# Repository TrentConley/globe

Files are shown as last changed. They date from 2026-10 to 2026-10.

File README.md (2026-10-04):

# Travel Globe · Engineering prototype A0

- [Travel appearance simulator](https://trentconley.github.io/globe/)
- [Actual CAD assembly](https://trentconley.github.io/globe/engineering.html)
- [Engineering report](https://trentconley.github.io/globe/engineering-report.html)
- [CAD/source package](https://trentconley.github.io/globe/engineering-package.zip)
- [Manufacture the first sample — quote packs and test plan](https://trentconley.github.io/globe/sample-plan.html)
- [Small optical prototype package](https://trentconley.github.io/globe/optical-prototype-A0.zip)
- [Engineering source](https://github.com/TrentConley/globe/tree/master)

The full globe is not yet fabrication-ready. Matrix-board routing, polar coverage and physical optical/electrical/mechanical qualification remain on hold. The ten-cell optical test board is routed and independently checked; supplier qualification of its candidate LED is still required. No physical globe has been built or tested.

This branch contains the public static build. Phone edits on the appearance simulator stay in browser storage; this site is not connected to a hardware globe.

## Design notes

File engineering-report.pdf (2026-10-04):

# Travel globe — engineering prototype A0

A 305 mm travel globe with 25× terrain and approximately 50-mile illuminated footprints. This release contains actual CAD, a fitted optical prototype, a routed test PCB, controller software, and reproducible engineering checks. The complete globe is not yet released for fabrication. The dense matrix boards still have unrouted connections, the south-polar support region needs a coverage revision, and the real optical finish has not been tested.

Open the actual CAD assembly (http://127.0.0.1:4173/engineering.html) · Download the engineering package (http://127.0.0.1:4173/engineering-package.zip) · Travel appearance simulator (http://127.0.0.1:4173/index.html)

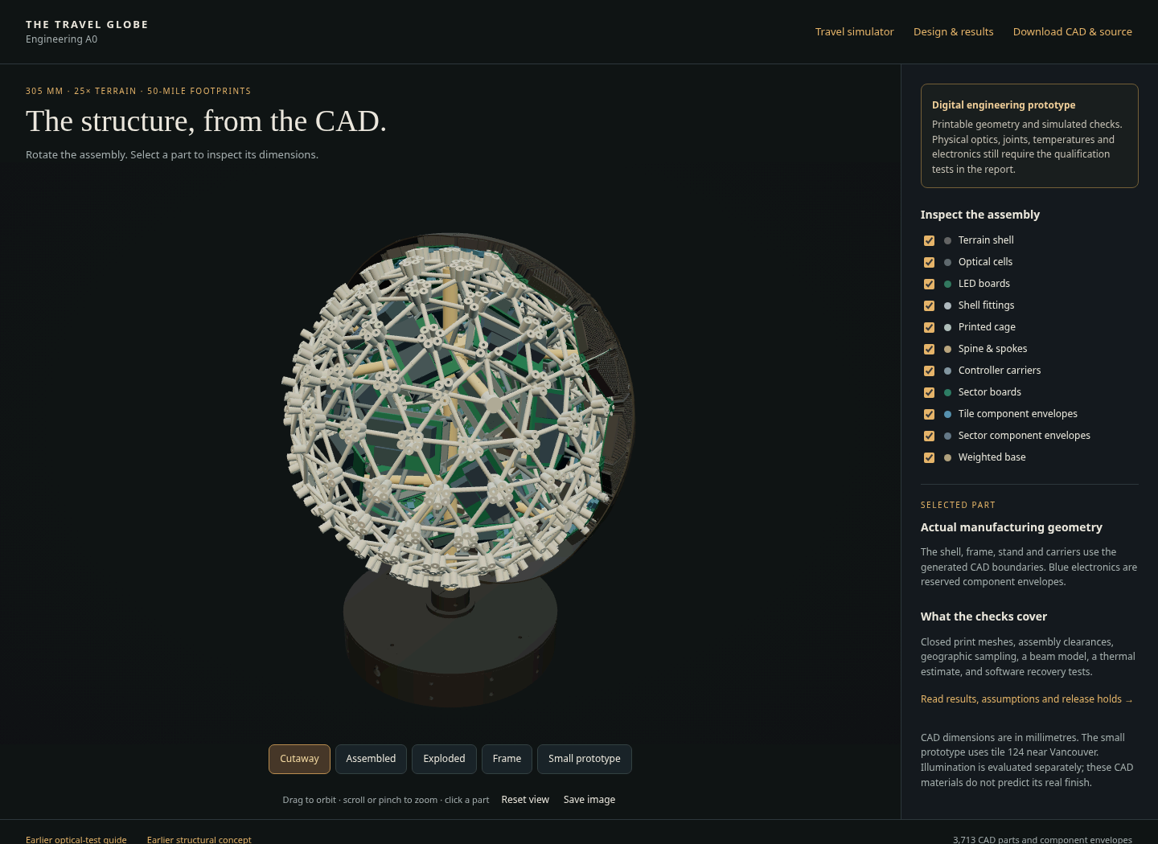
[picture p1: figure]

## What exists, and what the evidence means

Item | Status
Cage, stand, hubs, spokes, shell panels, baffles, controller carriers, prototype cradle | Parametric source and closed manufacturing meshes generated; assembly checks run
Terrain | Real sampled elevation, physically displaced at 25×; smooth inner sphere
Ten-cell optical test board | Routed; KiCad reports 0 violations and 0 unconnected items; Gerbers, drills, BOM and placement file included

Travel Globe A0 · Digital engineering prototype · 1 / 14

Item | Status
Six full-globe matrix board shapes | Placement, electrical connectivity and channel maps generated; routing incomplete — do not order
Mechanical simulation | Linear beam screening with a 3.5 kg supported mass; rigid-joint assumption
Thermal simulation | Two-node heat-balance estimate; no calibrated CFD or measured prototype temperatures
Optical simulation | Geometric apertures and parameter sensitivity; no measured resin, paint or LED data
Device software | 14 automated tests passed, including simulated transactions, interrupted storage, CRC errors and shutdown faults
Browser CAD viewer | Desktop and phone controls tested; reads actual generated meshes
Physical assembly, light output, print fit, component pinout/current, electrical commissioning | Not performed

The CAD viewer is an inspection tool. Its colors are material illustrations; it does not certify the finished globe's brightness or surface appearance. The travel simulator remains an ideal appearance preview.

## 1. Architecture and scale

At this scale, 50 miles is 1.926 mm of surface radius, or 3.852 mm across. A 2 mm planar LED grid becomes slightly wider at the spherical surface. A visited city is consequently a small group of cells, often one to five commanded emitters. Two nearby visits can merge. There are no connecting route lines and no country-wide fill.

The structure uses a frequency-four icosahedral lattice: 320 triangular tile positions, 162 frame nodes and 480 struts. Detailed Natural Earth coastlines select 226 populated tiles containing 33,406 emitters. Six repeated PCB/baffle shapes cover these positions. Many emitters on coastal boards remain off. The denser coastline data adds small-island coverage that the earlier coarse mask missed.

Twenty removable terrain panels correspond to the original icosahedron faces. Eight PA12 cage sections bolt together around a central aluminum spine. Ten aluminum spokes connect two split hubs to the cage. Twenty service carriers hold the sector electronics inside the cage. A weighted base supports the spine without bearings or a motor.

Nominal parameter | A0 value
Sea-level outside diameter | 305 mm
Smooth shell inside radius | 151.5 mm
Terrain exaggeration | 25×
Maximum sampled relief | Approximately 3.73 mm
Shell radial thickness | 1 mm at sea level, up to approximately 4.73 mm under the highest sampled relief
PCB corner radius | 144.5 mm
PCB thickness | 1 mm
LED pitch / optical opening at board | 2 mm / 1.6 mm

Travel Globe A0 · Digital engineering prototype · 2 / 14

Nominal parameter | | A0 value
Optical wall thickness | | 0.4 mm
Nominal baffle-to-shell clearance | | 0.35 mm
Nominal minimum panel-edge separation | | 0.5 mm
Cage vertex radius / strut diameter | | 132 mm / 3.6 mm
Spine | | 12 mm OD × 8 mm ID, 314 mm long
Spokes | | 8 mm OD × 4 mm ID aluminum tube
Base body | 200 mm diameter × 36 mm high, before feet
Steel ballast | 150 mm diameter × 6 mm thick, approximately 0.819 kg

All CAD coordinates use millimetres: +Z north, +X at latitude 0/longitude 0, +Y at longitude 90° east. The geometry
lies in its assembled coordinate system unless the filename begins | prototype- | or identifies a reusable local tile
part. Do not rescale STLs to inches.

## 2. Build the optical prototype first

This is the concrete first fabrication package, using tile 124 near Vancouver. It tests the real curvature, actual 2 mm lattice, magnetic seating and 25× terrain. Its simple ten-channel circuit avoids depending on the unfinished full-globe matrix PCB.

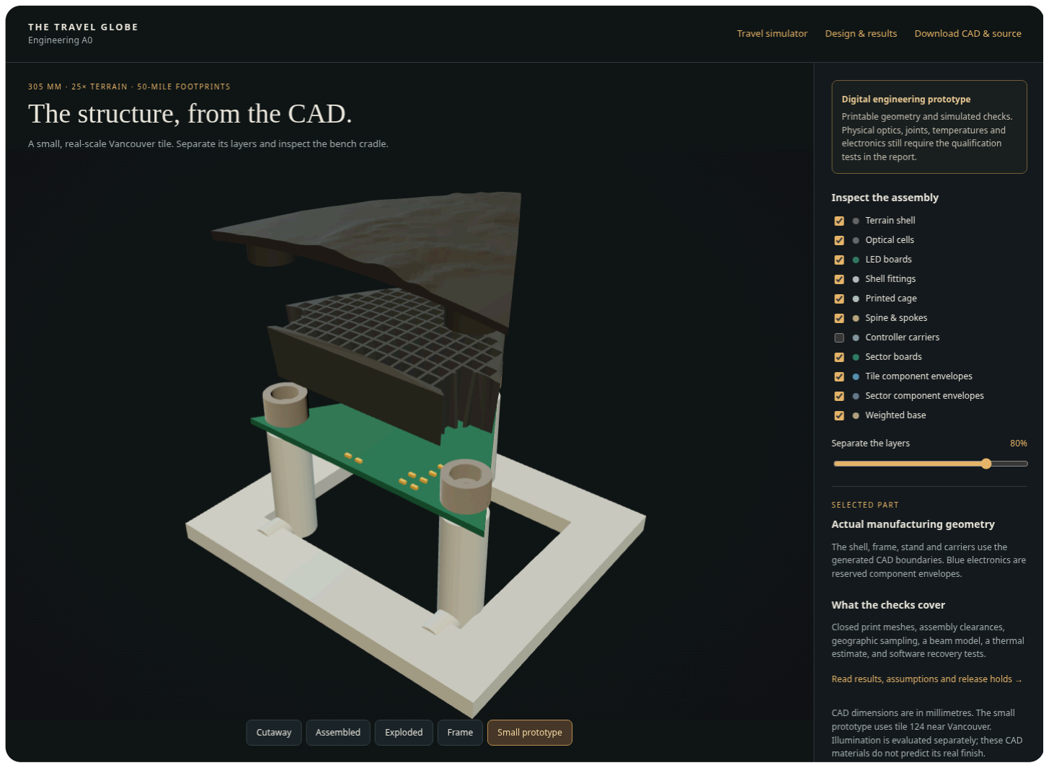
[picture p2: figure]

Travel Globe A0 · Digital engineering prototype · 3 / 14

Order or make the following:

Part | Quantity | Process

prototype-shell-vancouver-25x.stl

### 1 Clear/translucent SLA resin; preserve the smooth inner optical surface

prototype-shell-himalaya-25x.stl

### 1 Same resin and finish; thicker-relief comparison coupon on identical

curvature

baffle-type-02.stl | 1 Opaque black SLA/DLP resin; qualify 0.4 mm walls and clean every cell
prototype-cradle-type-02.stl | 1 | PA12 preferred; a rigid print-service alternative is acceptable for this bench fixture
magnet-seat-M2-4mm.stl | 3 PA12, with the supplied fit coupon
magnet-fit-coupon.stl | 1 | Same process as the seats
Optical bench PCB, 1 mm FR4 | Small service minimum | Supplied two-layer Gerbers/drills; outsource the 0402 LED and 0603 resistor assembly
4 mm diameter × 2 mm magnets | 6 | Matched pairs; verify polarity before retention

M2 × 22 countersunk screws and
M2 nuts

### 3 each The bench cradle has deeper nut pockets than the globe frame; confirm

| | head geometry and engagement

Adhesive rubber feet, at least 2 mm thick

### 4 Under the cradle; keep projecting screw tips clear of the table

Raspberry Pi Pico, USB cable, fine
insulated wire

### 1 set Bench control; no 12 V supply is used in this test

The bench BOM names Kingbright APHHS1005SYCK as a candidate amber/yellow 1005 LED. Its current manufacturer datasheet and polarity must be confirmed by the assembler. A nominal package name alone is not enough to approve substitution. The resistor is 1 kohm, 1%, 0603; RC0603FR-071KL is a suitable nominal specification. These components have not been physically tested here.

The bench board has only ten populated emitter positions. It cannot display arbitrary geography across the whole tile. The supplied Vancouver, Seattle, combined and individual-cell patterns use the selected positions. The cell spacing and optical stack are the same as the proposed full-globe design.

Assembly sequence:

1. Measure the print coupon's magnet pockets. Choose a retained fit that does not crack the part. Check baffle openings for cured resin or supports; do not coat or fill them.
2. Inspect the assembled PCB under magnification. Have the service verify cathode orientation. With power disconnected, confirm that no solder pad has a direct short to ground and that each drive pad reaches its LED through a 1 kohm resistor.
3. Connect board pad 0 to Pico GP0, 1 to GP1, continuing through 9 to GP9. Connect the board's GND pad to a Pico GND pin. The pad number denotes the GPIO, not the Pico's physical header-pin number. Solder from the rear and add strain relief to the cradle; do not pull on the small pads.
4. Install MicroPython on the Pico. Copy | firmware/ten-cell-bench/main.py | and | patterns.json | with
Thonny. The initial power-on state is off. In Thonny's Shell run | import main; main.show('walk-0', 0.1)
and repeat through | walk-9 | . Check every expected cell before fitting the shell.

Travel Globe A0 · Digital engineering prototype · 4 / 14

5. Seat three nuts in the cradle, install the PCB and magnet seats, and lightly seat the M2 × 22 screws. Fit the rubber feet so the screw tips cannot touch the table. The globe frame uses shorter M2 × 14 screws; do not interchange them. Use the printed post height to support the board; do not flex it to make a screw engage. Stop if the head or nut binds.
6. Fit the black baffle at its modeled position, with a nominal 0.1 mm bottom allowance above the PCB. Small removable dots at the outer edge may retain it. Keep adhesive out of cells and away from components.
7. Fit the magnets with paired polarity. The 5.0 mm seating rim is the mechanical stop; the frame magnet face is recessed at 4.8 mm. The mating shell boss seats on the rim, leaving a nominal 0.2 mm magnetic gap. Qualify removable retention before relying on the magnets to carry a panel.
8. Test the uncoated shell first: | main.show('vancouver', 0.1) | , then | seattle | , then | both | . A PWM level of 0.1
is a starting point, not a calibrated brightness match. | main.show('off', 0) | turns it off. The selected bench
pattern is saved for restart.
9. Apply a controlled transparent charcoal/smoke finish to a flat coupon and one shell. Start with a thin coat; record the product, dilution, number of coats and cure. An opaque black paint can make this design unusable. Compare a matte clear topcoat separately.
10. Repeat with the raised Himalaya coupon. Inspect whether thick relief becomes too dim or spreads light between cells. Keep fixed camera exposure when comparing samples.

The GPIO outputs are current-limited by the series resistors. Never connect this passive test board to the globe's 12 V rail. Its power comes from the USB-powered Pico's logic outputs. Outsourcing the tiny surface-mount assembly keeps the user's work to basic soldering and mechanical assembly.

## 3. Optical acceptance criteria

Do not infer optical success from the browser. The deep black cells reject most off-axis LED light. The Monte Carlo study predicts roughly percent-level direct passage through representative channels; measured LED intensity and finish transmission determine whether the result is attractive.

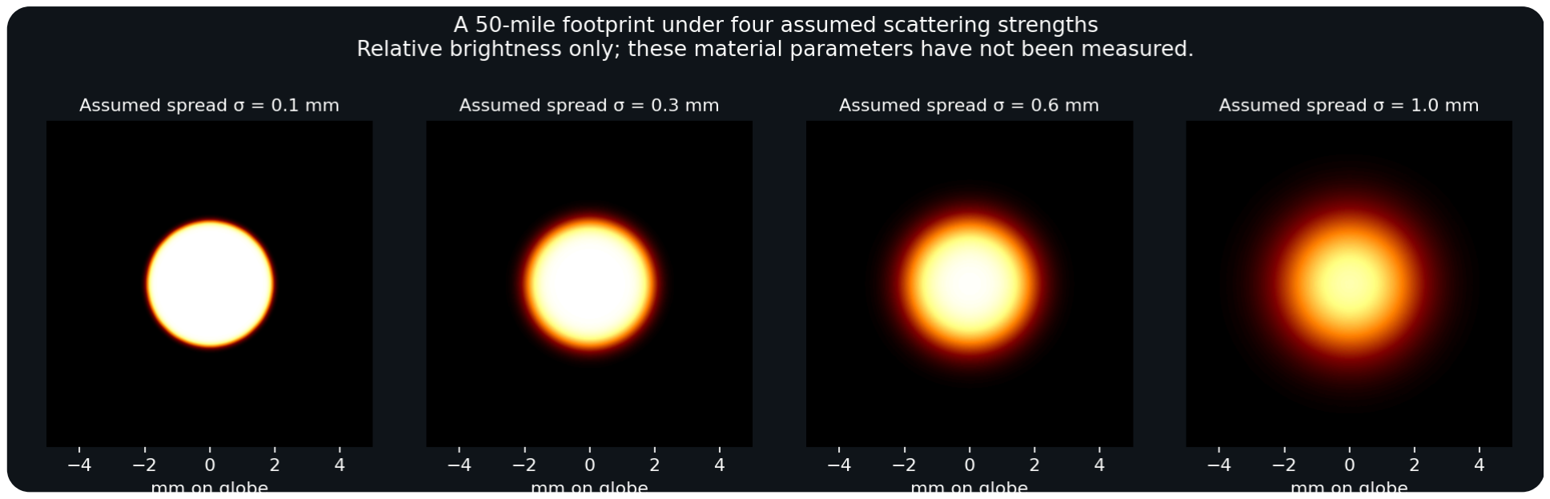
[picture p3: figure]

The shell's smooth inner surface makes the baffles repeatable but gives raised mountains a thicker light path. The absorption sweep quantifies the risk: increasing thickness from 1 to 4.73 mm leaves approximately 83%, 47%, 15%, or 2% of the flat-region transmission for assumed absorption coefficients of 0.05, 0.2, 0.5, or 1.0 per mm. Those coefficients are examples, not measured resin properties. Clear resin with a controlled outer tint is the starting material hypothesis.

Record these results in the supplied test log:

Travel Globe A0 · Digital engineering prototype · 5 / 14

At normal home viewing distance, Vancouver is a recognizable local patch and the neighboring unvisited cells stay dark enough to preserve its location.
Vancouver and Seattle can be recognized separately, and together create an understandable combined area without implying all of Canada is visited.
Individual lit cells do not make the entire shell glow. As an initial measurable target, the brightest adjacent uncommanded cell should stay below 15% of the commanded cell under fixed exposure.
A finished, unlit coupon looks charcoal rather than translucent white. The illuminated finish reads warm amber in the intended room lighting.
Raised terrain remains visibly lit. A starting comparison target is at least 40% of the nearby flat-region brightness before deciding whether electronic compensation is needed.
The baffle fits without pushing the shell outward. The seating rims, not the baffle walls, carry the shell. Record DC current, PWM setting, warm-up time and surface temperature for each comparison. Assess by eye as well as photographs; an attractive display is the purpose of the test.

If these fail, change resin/finish, optical opening, cell height or emission current and rerun the small test. A conformal thin-wall terrain shell is a possible later redesign, but it is not what these CAD files contain. After the small test passes, print one full-size terrain panel to check warpage and seam fit before ordering all twenty.

## 4. Full-globe mechanics and assembly

Use SLS/MJF PA12 for the cage, hubs, base parts and controller carriers. Material properties in the structural model are assumed lower-bound values, not print-service certification. The optical shell and baffle need different materials and finishing processes. Do not substitute opaque nylon for a light-transmitting shell.

The cage is split across three coordinate planes with a 0.05 mm modeling gap and twelve bolted side flanges. Unsupported sub-0.6 mm seam remnants are explicitly relieved and recorded in the mesh audit. PCB posts accept bottom-loaded M2 nuts; their support rods continue into the post above the nut recess. Bolt bores clear the projecting screw tips.

The purchased metal parts require cutting and drilling. The spine's 6 mm cable-exit port is 46 mm above its lower end, through one wall. Deburr it and fit abrasion protection. The base collar has an annular shoulder that carries the tube and a central wire passage. Spoke cut lengths and cross-hole centers come from the STEP/drawing files; use a drill jig to keep the two end holes aligned. The 8/4 mm spoke tube was selected to increase margin around the drilled joints.

Travel Globe A0 · Digital engineering prototype · 6 / 14

A0 mechanical dimensions · millimetres

Nominal dimensions from the CAD. Shop to confirm stock, drilling tolerance, edges and fitted joints. Ø305 sea level

376.5
before relief / feet

Ø200 base × 36

Hub center planes: Z = ±59.032
Globe center: Z = 0; base bottom: Z = −224 Spine end coordinates: −186 to +128 Purchased non-slip feet: qualify near R94

Spine · 12 OD / 8 ID

314

46

Ø6 cable port, one wall; deburr + grommet

### 10 spokes · 8 OD / 4 ID

102.264 cut length

Ø2.2 holes: 3.000 from hub end, 3.200 from cage end. Drill both walls. Hole axes parallel to assembled +Z.

Optical stack · local tile coordinates
PCB rear −1.0 · LED face 0 · package ~0.45 Seat head counterseat ~1.7 · magnet face 4.8 Seat rim / shell boss contact 5.0
Shell inner R151.5 · baffle top R151.15
Shell radial wall 1.0 to ~4.73 at 25× terrain

Fit-critical dimensions require the small coupon and measured supplier tolerances.

No general manufacturing tolerance is implied by decimal precision. Use a jig for short end distances.
The beam analysis omits hole stress concentration and joint slip. Proof-test the drilled tube / socket joint.
STEP defines the ballast holes and actual supports. This drawing is a dimensioned reference, not a certified fabrication release.

metal-cut-list.csv records the 102.264 mm nominal spoke length and the two cross-hole positions. Decimal precision describes the model, not a guaranteed manufacturing tolerance. The short distance from each hole to the tube end needs a drilled-joint proof test. Confirm fit before drilling all ten tubes.

Dry-assemble in this order: ballast and base; spine and two split hubs; ten spokes; eight cage sections; controller carriers; wiring trunks; populated PCB tiles; local optical baffles; magnet seats; terrain panels. Keep the base lid accessible until commissioning is complete. Install electronics and prove the light patterns before closing the shell.

The controller carriers have open saddles facing the cage. Push each onto its specified struts from inside, then retain it with 2.5 mm cable ties. Their 60 × 40 mm perfboards are double-sided assemblies: Pico inward, regulator/mux/transceiver outward. Module envelopes are reservations, not verified supplier STEP models. Clip and insulate solder leads so they cannot contact the Pico or cage. Verify actual purchased module dimensions before populating all twenty carriers.

Each populated tile has three supports. Ordinary PCB screws use the 1 mm head spacer to keep the head above the LED packages. At shell anchors, the magnet seat replaces this spacer. Anchors on an unpopulated ocean tile use a 1 mm dummy spacer in place of the absent PCB. There are sixty shell anchors in total. Preserve access to the screw beneath each magnet: qualify a removable retention method, not an irreversible fill of the screw cavity.

The nominal 0.5 mm panel seams and 0.35 mm baffle clearance are tolerance allowances. Confirm them against the service's cured dimensions, not just printer layer height. The three seating rims establish each shell panel's radial position. Magnetic friction and retention still need pull and service-cycle tests. Do not tighten a panel into place by bending it.

Travel Globe A0 · Digital engineering prototype · 7 / 14

## 5. Electronics and wiring

The full-globe architecture uses a Pi Zero 2 W in the base, twenty Pico sector controllers, one TCA9548A multiplexer per sector, and an IS31FL3741 per populated tile. Each sector has four independent I²C branches with
at most four tile addresses. | tile-schedule.csv | specifies every tile, board shape, multiplexer branch and address
jumper.

The full matrix boards are unfinished engineering candidates. Their pad-level netlists and placement files are included for review; full-globe Gerbers are deliberately absent. R_EXT is a provisional 2.2 kohm reference value and the firmware starts with current code 4. Current codes are not milliamps. Confirm the manufacturer specification, actual scan behavior, shutdown-pin behavior, thermal path and measured current before changing the current setting or releasing a batch.

A0 power and communications wiring

Low-voltage topology. Full-globe electronics remain on hold pending layout and hardware qualification.

External 12 V / ~36 W

Certified enclosed adapter M8 inlet → 2 A main fuse

INA260 0x40

IN+ from fused 12 V
IN− to relay COM; GND common

Normally-open relay

COM → NO only on enable
DC-rated 5 V coil candidate

Two power branches

A: 750 mA fuse → 10 sectors B: 750 mA fuse → 10 sectors 12 V, GND trunk
350 mA PTC at each sector

Independent 5 V regulator

From fused 12 V before relay Powers Pi and relay coil
Qualify 5 V / 2 A capacity

Pi Zero 2 W

GPIO2 SDA / GPIO3 SCL
GPIO17 → 1k → NPN base
USB → RS-485 adapter
FRAM 0x50 on 3.3 V I²C
Common low-voltage GND

Relay coil driver

+5 V → coil → NPN collector Emitter to GND; 100k B–E
Flyback diode across coil
Cathode at +5 V
Never drive coil from GPIO

Each sector ×20

350 mA PTC → 3.3 V buck
3.3 V → tile / logic rail
Schottky diode → Pico VSYS USB isolated from tile rail DS18B20 local sensor

One RS-485 daisy chain

Master end: 120 Ω termination
Bias once: 330 Ω A→3V3, B→GND Twisted pair A/B plus ground reference 120 Ω only at final sector; verify A/B

Sector Pico + 3.3 V transceiver

GP4 TX → DI; GP5 RX ← RO
GP6 → DE and /RE; 10k pull-down GP15 → DS18B20 data, 4.7k pull-up GP10–13 → branch SDB; 10k down

TCA9548A at 0x70

GP0 SDA, GP1 SCL; 100 kHz
GP14 reset + 10k pull-up; A0–A2 GND Upstream pull-up pair (account for module) 4 downstream buses × ≤4 addresses

One branch → tile daisy chain

6-pin JST-SH: 1 3V3 · 2 GND · 3 SDA 4 SCL · 5 SDB · 6 INTB provision
One 2.2k SDA/SCL pull-up pair per bus Exactly one JP per tile: 0x30–0x33 Target total branch cable ≤350 mm

Ten-cell bench is a separate, simple circuit

USB → Pico only; GP0–GP9 → matching pads 0–9
Each pad → 1 kohm resistor → one LED anode; all cathodes → common GND No matrix IC, 12 V input, relay or sector controller is used for this test
Load firmware/ten-cell-bench; outsource the tiny surface-mount assembly

Harness: use the tile, sector and I²C schedules. Check continuity and polarity before power.

Route the two fused +12 V feeds, ground and RS-485 pair through the deburred spine port. Add strain relief.
Power trunk: nominal AWG24; pair: flexible twisted insulated wire. Confirm voltage drop, connector current and cable fit. The software guard is not a certified safety circuit. Fuses, PTCs, external pull-downs and hardware fault tests are required. SDB / I²C behavior, real module envelopes, electrical schematic/ERC and full matrix routing remain release holds.
Tile connector pin | Signal

### 1 Local regulated 3.3 V

### 2 Ground

Travel Globe A0 · Digital engineering prototype · 8 / 14

Tile connector pin | Signal

### 3 SDA

### 4 SCL

### 5 Branch SDB shutdown

### 6 INTB, open-drain diagnostic provision; not used by A0 control software

Both tile connectors carry the same signals. Use precrimped 6-way JST-SH leads; confirm pin numbering at both ends rather than trusting wire colors. Bridge exactly one address jumper: JP1 = 0x30/GND, JP2 = 0x31/SCL, JP3 = 0x32/SDA, JP4 = 0x33/3.3 V. Address-to-SCL/SDA selection is a property of this IC; do not apply this scheme to an arbitrary replacement driver.

Sector Pico connection | Destination
GP0 / GP1 | TCA9548A SDA / SCL, 100 kHz
GP14 | TCA reset; active low, held high in normal operation
GP10–GP13 | SDB for mux branches 0–3
GP4 / GP5 | RS-485 transceiver DI / RO, UART1 at 115200 baud
GP6 | Joined DE and active-low RE
GP15 | DS18B20 data, 4.7 kohm pull-up to local 3.3 V
VSYS | Local supply through a Schottky isolation diode
GND | Common low-voltage ground

Use a 3.3 V MAX3485/SP3485-class transceiver, not a 5 V MAX485 module. A TCA9548A breakout such as Adafruit 2717 is a candidate; account for its installed pull-ups. Use one 2.2 kohm pull-up pair on each downstream branch and one upstream pair, rather than allowing every tile to add another pair. The harness schedule provides a wiring order and length allowance; confirm total branch length below the 350 mm design target and measure rise time during commissioning.

Use a 12 V trunk with local regulated 3.3 V converters; a D24V10F3-class module is the candidate envelope. Feed a Pico's VSYS through a Schottky diode so connecting USB cannot drive the shared 3.3 V LED rail backward. Flash and configure Picos with tile harnesses disconnected. Each sector input has a 350 mA PTC. Two base fuse branches, nominally 750 mA each, feed the twenty sectors. The current sensor and normally-open relay control the lighting branches, not the Pi's own supply.

RS-485 is one daisy chain. Terminate only its two physical ends with 120 ohms: the master end and the last sector
in | sector-harness.csv | . Install the idle bias once at the master, nominally 330 ohms from A to 3.3 V and 330 ohms
from B to ground. Include a ground reference with the twisted pair. Check the particular transceiver's A/B naming and idle receiver level before connecting all sectors.

The base uses a certified external 12 V, approximately 36 W adapter, a fused DC inlet, a separate 5 V Pi regulator, and a normally-open relay switched by a transistor with a flyback diode. A G5Q-1A4-DC5-class relay is the candidate mechanical envelope. The Pi drives its transistor through a resistor from GPIO17, with an external base/gate pull-down so boot or shutdown leaves the relay off. The relay must be rated for the actual DC load. A 2 A main input fuse and protected branches remain necessary independently of software.

Travel Globe A0 · Digital engineering prototype · 9 / 14

An INA260 at Pi I²C address 0x40 monitors the 12 V lighting branch. The software latches off above 12 W, above 1.2 A, outside 10.8–13.2 V, on invalid readings, or on sensor failure. A separate thread monitors it during slow display updates. A local DS18B20 in every sector prevents operation without a valid reading and blanks that sector at 50 °C. Sensor placement must follow the hottest measured location, not just the easiest mounting point.

The current sensor is upstream of the normally-open relay so it can measure supply voltage before enabling the load. External pull-downs hold the relay transistor, SDB pins and RS-485 DE low during reset. An OS hang is not covered by a certified hardware watchdog; that fault must be tested and may require an independent watchdog. The base electronics tray still needs a qualified retention method, actual module fit and cable strain relief. The drawing is a wiring topology, not an ERC-checked full-system schematic.

## 6. Persistent records and phone control

The physical-device service runs on the Pi on the home network. Open its local address from a phone or computer and enter the device key stored on that Pi. Add a place by name and coordinates, set the footprint radius, and save. The default radius is 50 miles. JSON import/export supports a separate backup. The public GitHub site is a viewer, not a connection to a powered globe.

firmware/install/README.md includes desktop simulation, Pi provisioning, the systemd service, Pico file placement, configuration checks and recovery instructions. The A0 service is for the trusted home LAN; it has not been deployed on a physical Pi in this work.

SQLite uses WAL journaling and synchronous FULL commits. Writes require the current revision to prevent two windows silently overwriting one another. The latest project is rendered again after startup. The Pi also writes a two-bank MB85RC256V-class 32 kB FRAM recovery record at I²C address 0x50. CRCs and a final commit marker reject interrupted records. Acknowledgment follows the recovery write's readback verification.

FRAM preserves up to 2,000 coordinate pairs, radius and brightness. Names and history remain in SQLite and the exported JSON. If recovery from FRAM is needed after SD-card corruption, the coordinates return with generated names. Use an endurance SD card and retain an independent export. Automated tests simulate process termination and interrupted byte writes; they do not replace repeated physical unplug/restart tests on the selected SD card and FRAM module.

The wire protocol includes a CRC, revision number and bounded payload. A sector displays a frame only after receiving every configured tile for that revision. Stale updates and an incorrect pixel-map digest are rejected. Loss of host contact blanks the sector after sixty seconds; the stored travels are retained. This is a display-fault response, not deletion of the user's record.

The physical renderer samples open cell area and includes mounting shadows. A minimum local mark prevents a small visit disappearing beside a post. This can place the nearest illuminated cell within approximately 90 miles at the 50-mile setting. It does not illuminate an entire country. Unsupported places are reported explicitly. A0 excludes the south-polar support tiles; it does not yet provide continuous Antarctic coverage. The geographic diagnostic is not a measure of the percentage of Earth explored.

Travel Globe A0 · Digital engineering prototype · 10 / 14

## 7. Mechanical, thermal and geographic results

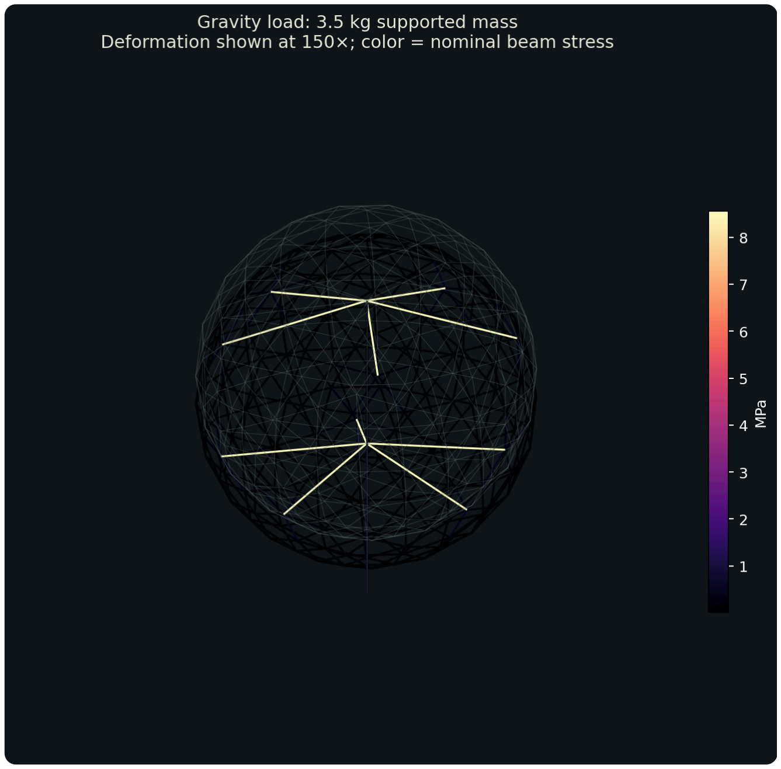
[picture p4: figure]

The final 8/4 mm spoke model uses a 3.5 kg supported load against an estimated approximately 3.15 kg component mass. It predicts about 0.16 mm maximum displacement under gravity, 0.48 mm under a static 3g load, and 0.90 mm with gravity plus a 5 N side load at the north pole. Maximum nominal aluminum beam stress is approximately 25.7 MPa in the 3g case. These are model outputs, not measured deflections.

The solver reproduces the independent cantilever formula for a 100 mm aluminum tube under a 1 N end load. Equilibrium residuals are checked. It assumes tight, rigid joints and omits local holes/notches, bolt preload/slip, print anisotropy, nonlinear impacts, and long-term creep. Those omissions are why the report does not claim a validated drop rating or certified safety factor.

The idealized ballast/base calculation gives approximately 29° static tip angle and roughly 11.5 N top-side force to tip, before measured mass distribution and floor friction replace the assumptions. Use non-slip feet near the base perimeter. Test tipping gradually with the prototype supported against a fall.

Travel Globe A0 · Digital engineering prototype · 11 / 14

The thermal estimate uses 12 W inside the globe in a 30 °C room. It predicts approximately 40 °C interior and 35 °C outer surface under the stated convection/radiation assumptions. A poorer heat-transfer case reaches approximately 47 °C inside. Local component hot spots, sunlight and measured material emissivity are not resolved. Run instrumented warm-up and fault tests before accepting a 50 °C shutdown threshold or leaving the finished display powered unattended.

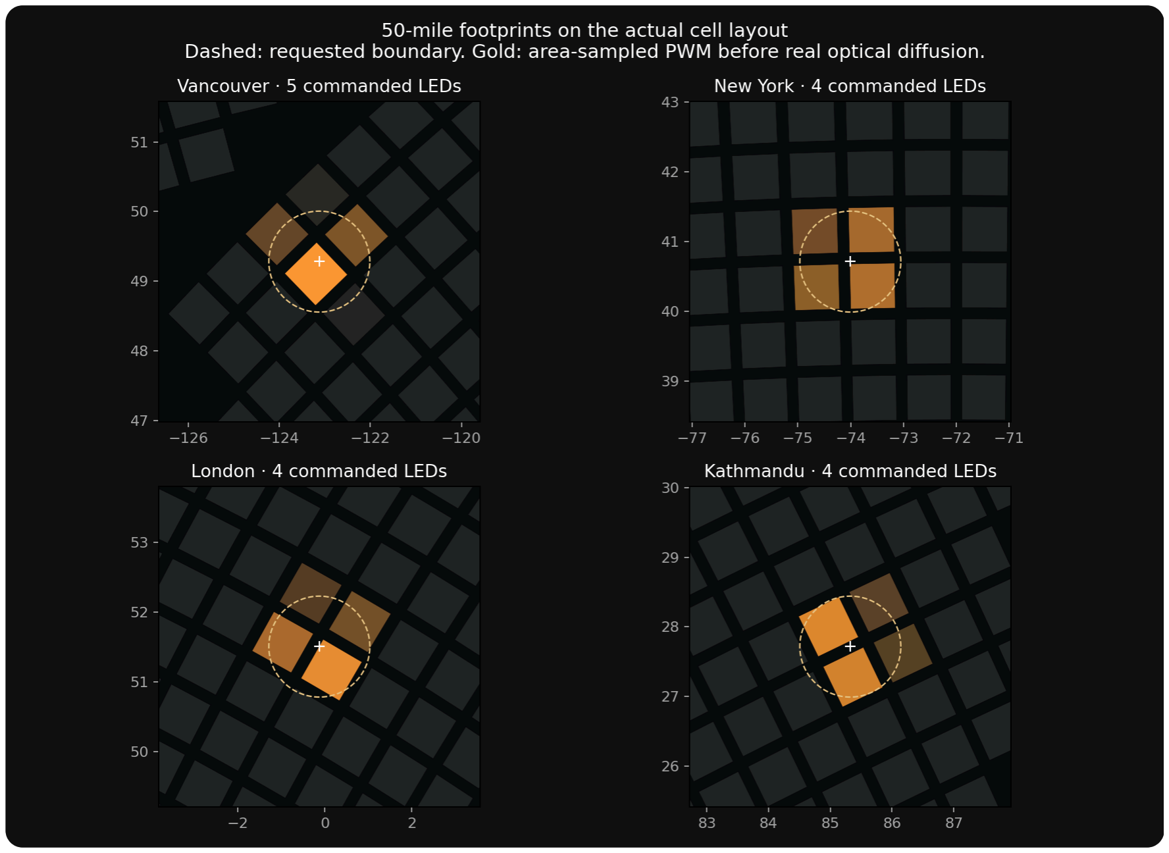
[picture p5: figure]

The city study uses Vancouver, Seattle, New York, Chicago, Los Angeles, Sioux Falls, London, Tokyo, Sydney, Reykjavik, Honolulu, Singapore and Kathmandu. The revised sampling commands at least one local cell for every example. The report also records the substantial polar coverage limitation; it is not hidden by the successful city examples.

## 8. Budget and procurement

The confirmed budget is $1,500–$4,500. This design targets the upper end. | budget-allowances.csv | allocates
exactly $4,500, including $250 for the optical prototype and $550 contingency. These are procurement ceilings, not supplier quotes. The largest ceiling is $1,700 for all 226 assembled LED boards; whether a supplier can meet it with qualified components is unproven. A complete build at $1,500 is not established by this design.

Request a quote using the actual part counts, material requirements and fabrication files. Do not send the incomplete matrix candidates as manufacturing Gerbers. Ask print services to quote the baffles nested in batches, verify 0.4 mm walls, specify cured dimensional tolerances and state whether optical surfaces can be supplied without support scars. Price the finish and sample failures separately from raw printing.

Travel Globe A0 · Digital engineering prototype · 12 / 14

The package includes | electronics-and-hardware-bom.csv | , | parts-manifest.csv | , | metal-cut-list.csv | , | tile-
schedule.csv | , | sector-harness.csv | , | i2c-harness.csv | , | budget-allowances.csv | and | acceptance-
worksheet.csv | . Candidate modules and nominal screw lengths require fit review; they are not a prequalified
shopping cart.

Release gates are: the ten-cell optical/fit test; one full panel and frame-joint test; completed matrix routing/ERC/DRC and first-board electrical test; a working sixteen-tile sector; measured full-system power/thermal and persistence tests; then full assembly. If quotes or optical results exceed the budget, the design has to change before the production batch.

## 9. Qualification record and service

The included acceptance worksheet gives a place to record measured results. Minimum checks include individual-cell mapping and polarity; repeated shell removal; screw/nut fit; spoke and cage-joint proof loading; two-hour warm-up at maximum commissioned command; disconnected/invalid temperature sensor; lost RS-485 host; unplugged current sensor; a protected-branch fault using a current-limited bench supply; and repeated saves followed by power removal/restart.

For the full globe, require all mechanical intersections to be resolved, all board DRC/ERC items reviewed, every physical tile label to match the schedule, and every sector to pass its cell-walk pattern. A clean PCB DRC proves layout rules and connectivity, not part suitability or firmware correctness. A watertight STL proves mesh closure, not that a service can print a 0.4 mm wall successfully.

Keep the source, pixel-map checksum, sector configuration, travel backup and measured calibration with the object. The shell and lighting are separate: adding a destination changes stored data and PWM values, so the terrain does not need reprinting. Disconnect power before replacing a tile or removing the base. Preserve the tile's identifier and address jumper when fitting a replacement.

## 10. Files and reproducibility

The download includes parametric CAD source, STL parts, checked STEP exports where available, assembled geometry, engineering result JSON/figures, the ten-cell manufacturing pack, unfinished matrix candidates in a clearly marked hold folder, firmware, wiring schedules, and test instructions. Cage STEP exports are faceted boundaries; the Python source is the editable dimensional definition. A STEP that fails round-trip validation is excluded; its independently checked STL remains available.

Use | docs/cloud-setup.md | and | tools/build-design.sh | for the environment and build order. The simulator is
built with | npm run build | ; geometry checks use | npm test | ; device tests use Python's unittest discovery. Rebuilds
must regenerate the pixel-map checksum and all twenty sector configuration files together. Do not mix a firmware configuration from one map with board/channel files from another.

Elevation and shoreline provenance, the Adafruit reference attribution, KiCad library terms and other third-party notices are included in the package. This release does not claim that a physical globe has been printed, assembled, or tested.

## Direct downloads and inspection records

Complete CAD, sources, firmware, test board and schedules (http://127.0.0.1:4173/engineering-package.zip) Small optical prototype only (http://127.0.0.1:4173/optical-prototype-A0.zip)

Travel Globe A0 · Digital engineering prototype · 13 / 14

Printable engineering report (http://127.0.0.1:4173/engineering-report.pdf) Machine-readable release status (http://127.0.0.1:4173/engineering-checks/release-status.json) Parts and processes (http://127.0.0.1:4173/engineering-checks/parts-manifest.csv)
Electronics and hardware BOM (http://127.0.0.1:4173/engineering-checks/electronics-and-hardware-bom.csv) Metal cut list (http://127.0.0.1:4173/engineering-checks/metal-cut-list.csv)
Acceptance worksheet (http://127.0.0.1:4173/engineering-checks/acceptance-worksheet.csv)
Matrix-board routing hold (http://127.0.0.1:4173/engineering-checks/matrix-routing-hold.json)
Assembly intersection audit (http://127.0.0.1:4173/engineering-checks/assembly-intersections.json) Mechanical simulation outputs (http://127.0.0.1:4173/engineering-checks/structural-analysis.json) Thermal simulation outputs (http://127.0.0.1:4173/engineering-checks/thermal-analysis.json)
Download checksums (http://127.0.0.1:4173/engineering-downloads.json)

Optional large faceted STEP boundaries are separate from the main package. The checked STLs and parametric source are the primary cage definition. Octant 04 failed STEP round-trip validation and is not supplied as STEP.

Cage octant 01 — checked faceted STEP ZIP (http://127.0.0.1:4173/cad-step/cage-octant-01.step.zip)
Cage octant 02 — checked faceted STEP ZIP (http://127.0.0.1:4173/cad-step/cage-octant-02.step.zip)
Cage octant 03 — checked faceted STEP ZIP (http://127.0.0.1:4173/cad-step/cage-octant-03.step.zip) Cage octant 05 — checked faceted STEP ZIP (http://127.0.0.1:4173/cad-step/cage-octant-05.step.zip) Cage octant 06 — checked faceted STEP ZIP (http://127.0.0.1:4173/cad-step/cage-octant-06.step.zip) Cage octant 07 — checked faceted STEP ZIP (http://127.0.0.1:4173/cad-step/cage-octant-07.step.zip) Cage octant 08 — checked faceted STEP ZIP (http://127.0.0.1:4173/cad-step/cage-octant-08.step.zip)

A0 engineering prototype · 305 mm · 25× terrain · 50-mile footprints · No physical fabrication or testing performed.

Travel Globe A0 · Digital engineering prototype · 14 / 14

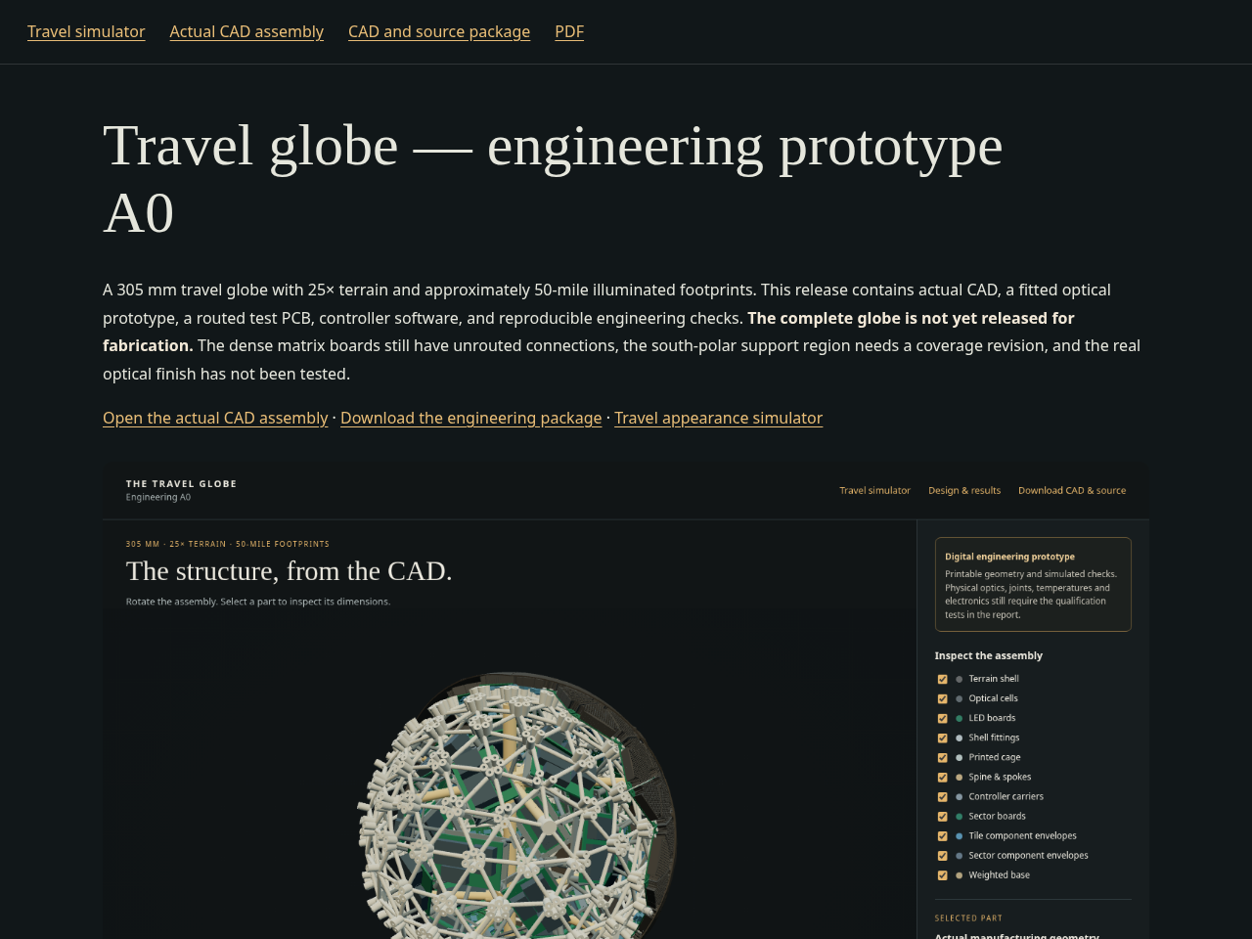
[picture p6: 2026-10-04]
engineering-assets/engineering-report-desktop.png

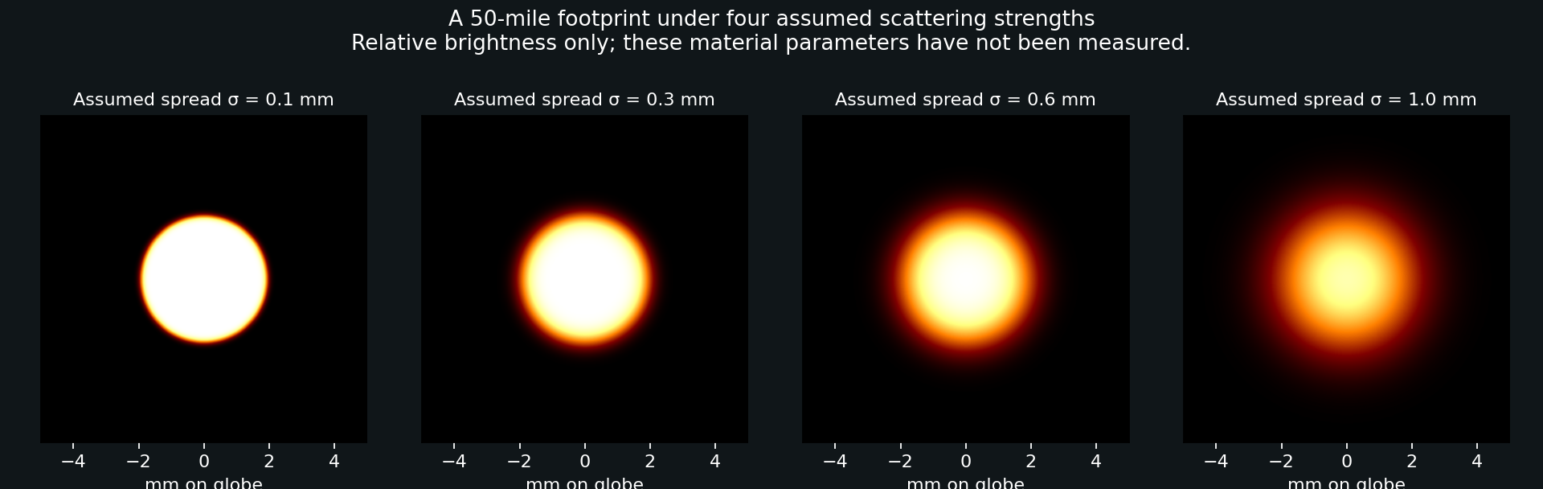
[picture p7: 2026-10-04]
engineering-assets/optical-sensitivity.png

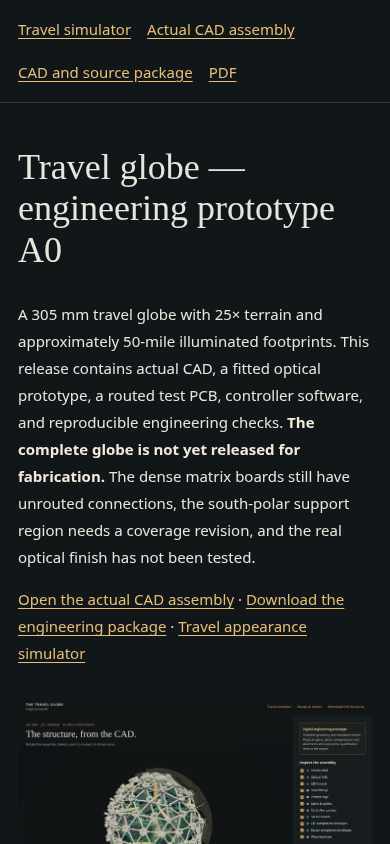
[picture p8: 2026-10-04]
engineering-assets/engineering-report-mobile.png

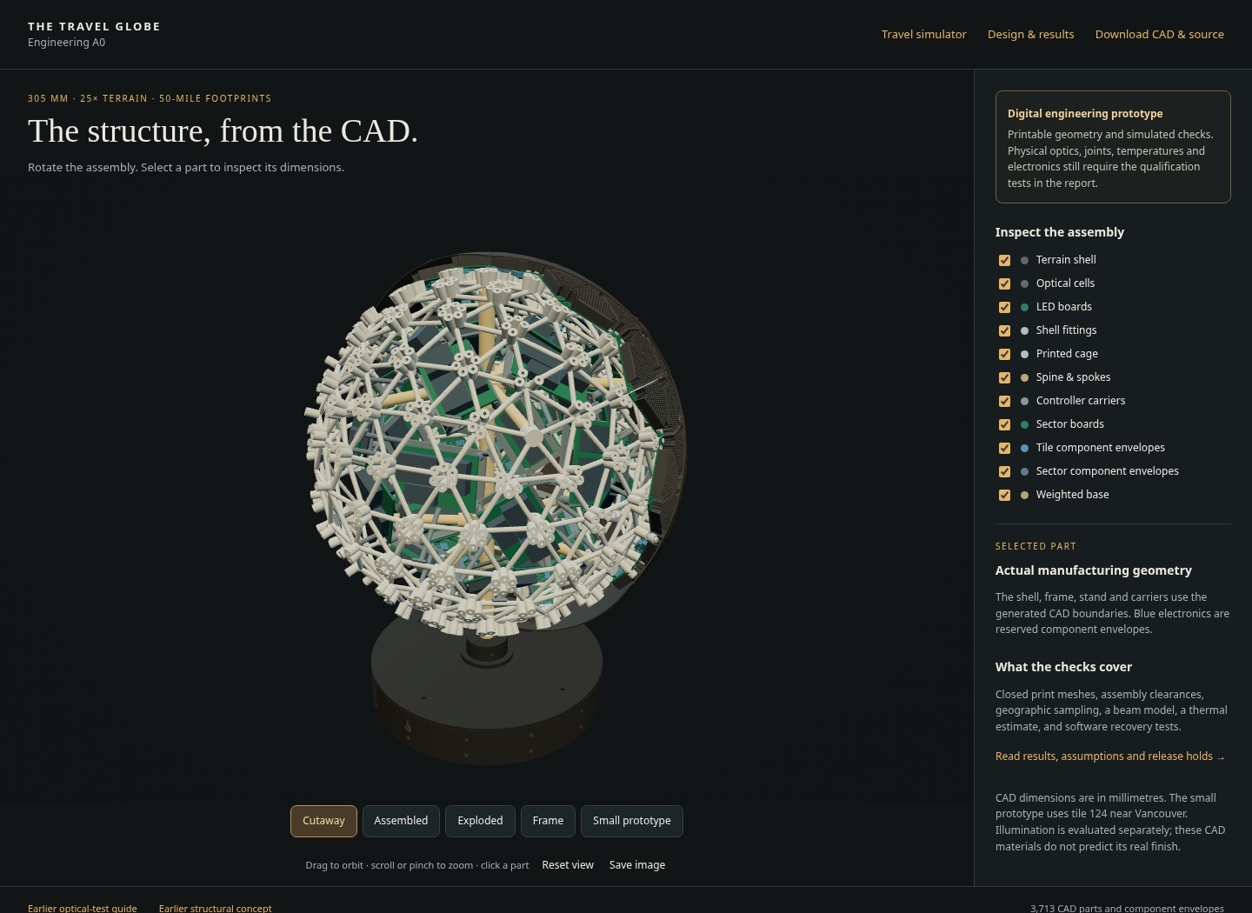
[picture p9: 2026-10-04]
engineering-assets/engineering-cutaway.png

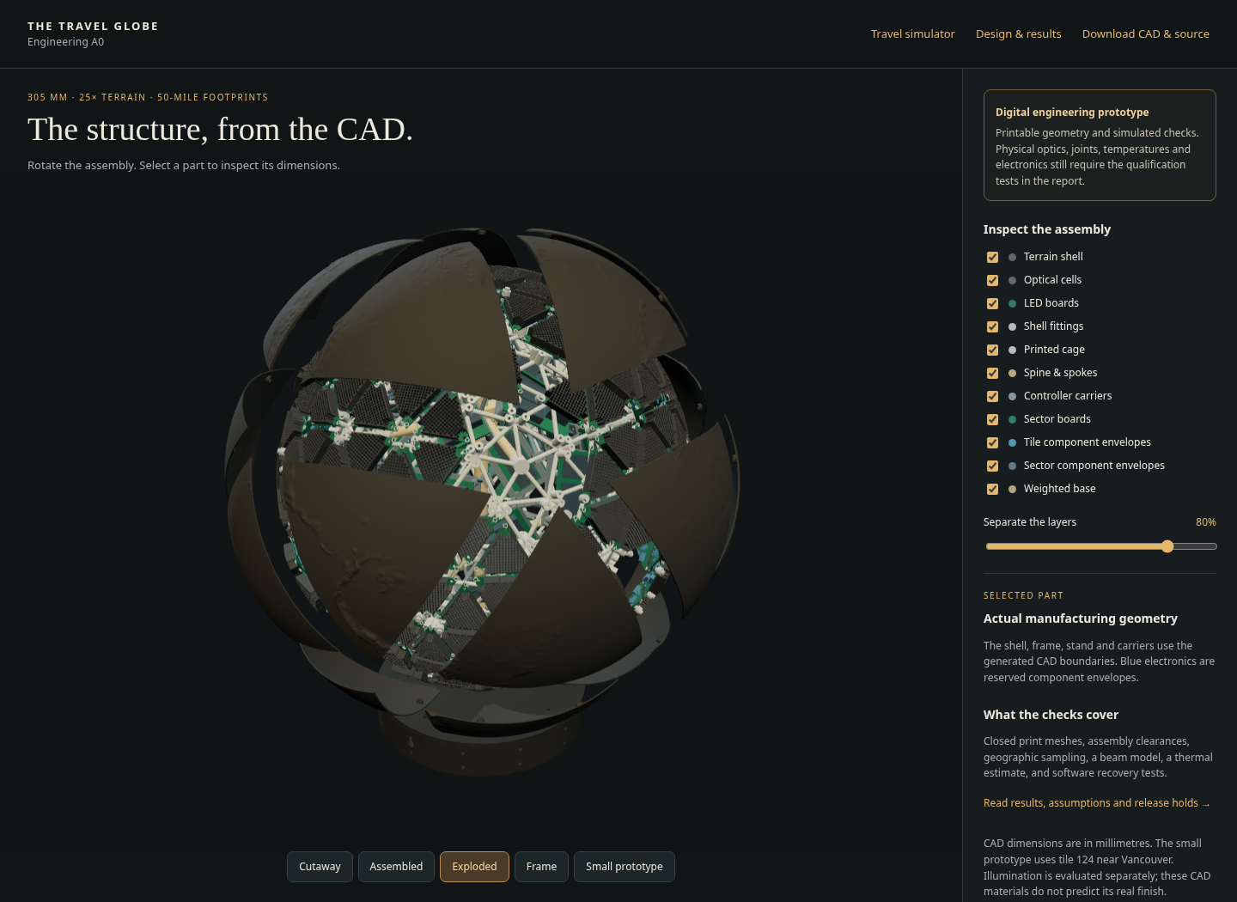
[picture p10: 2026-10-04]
engineering-assets/engineering-exploded.png

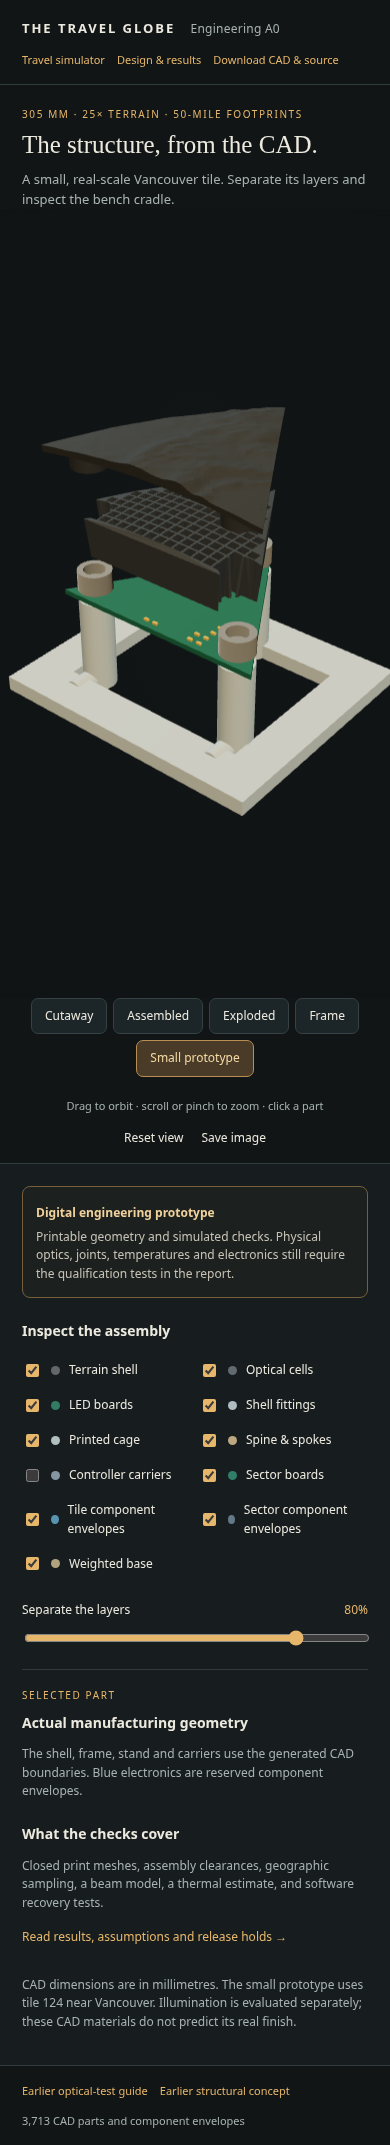
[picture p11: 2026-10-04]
engineering-assets/engineering-mobile.png

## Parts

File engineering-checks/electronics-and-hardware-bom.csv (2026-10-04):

item | quantity | specification | release_note
Matrix tile assemblies | 226 | 6 shapes; 33406 amber 1005 LEDs total; IS31FL3741 each | HOLD: routing incomplete
Pico sector controllers | 20 | RP2040 Pico; headers/USB access | Envelope / hardware qualification
I2C multiplexers | 20 | TCA9548A at 0x70; Adafruit 2717-class candidate | Verify module size and installed pull-ups
RS485 transceivers | 20 | 3.3 V MAX3485/SP3485; no automatic direction required | Verify pinout and A/B convention
Sector regulators | 20 | 12 V in, regulated 3.3 V; D24V10F3-class candidate | Verify output ripple, envelope and heat
Sector temperature sensors | 20 | DS18B20, 3-wire powered mode | Known-source parts; placement by thermal test
Sector PTCs | 20 | 350 mA nominal hold at specified ambient; >=16 V | Choose trip curve and derating
Pico isolation diodes | 20 | SS14-class Schottky, 1 A 40 V | Check drop and power-source isolation
Sector perfboards | 20 | 60 × 40 mm; four mounts at ±28/±18 | Double-sided assembly with insulation
I2C pull-up resistors | 200 | 2.2 kohm; up to 5 pairs/sector | Subtract installed breakout pull-ups
DS18 pull-up resistors | 20 | 4.7 kohm | One per sector
Reset pull-up resistors | 20 | 10 kohm | Check breakout reset network
SDB / DE pull-down resistors | 100 | 10 kohm; 5 per sector | Required during reset
RS485 terminators | 2 | 120 ohm | Only physical chain ends
Master idle-bias resistors | 2 | 330 ohm | One A pull-up and one B pull-down; verify logic
Pi controller | 1 | Raspberry Pi Zero 2 W; endurance microSD >=16GB | 64-bit OS, headers and USB OTG
USB RS485 adapter | 1 | Linux serial; documented 3.3 V bus / bias behavior | Disable duplicate termination/bias
FRAM breakout | 1 | MB85RC256V 32KB, 3.3 V, 0x50 | Qualify interrupted writes
Branch current sensor | 1 | INA260, 3.3 V I2C 0x40; 12 V bus sense | Install before relay
Base regulator | 1 | 12 V to 5 V, >=2 A candidate | Measure ripple/thermal; powers Pi+coil
Relay | 1 | G5Q-1A4-DC5-class SPST-NO, DC load rating | Candidate envelope, not certified assembly
Relay driver | 1 | 2N2222-class NPN, 1k base, 100k base-ground, 1N4007 flyback | Verify transistor pinout and coil current
External adapter | 1 | Certified enclosed 12 V 36 W, compatible connector | No exposed mains build
Main fuse / holder | 1 | 2 A at 12 V DC; suited fuse characteristics | Coordinate with supply/current limits
Branch fuses / holders | 2 | 750 mA at 12 V DC | Coordinate inrush and fault clearing
M8 bulkhead DC inlet | 1 | Fits diameter 8.2 mm wall opening; insulated | Verify mating adapter / current / polarity
Magnets | 120 | Neodymium diameter 4 × 2 mm | 60 matched pairs; retention/polarity test
PCB screws/nuts | 695 | M2 × 14 countersunk and M2 nuts | Fit trial; ordinary sites use head spacers
Cage seam bolts | 12 | M2 × 16 with nuts/washers | Verify actual grip and accessible assembly
Spoke retaining pins/bolts | 20 | M2 through diameter 2.2 holes; nominal 16 mm with nuts | Adjust to measured socket grip
Hub/collar clamp bolts | 6 | M3, nominal 40 mm with nuts/washers | Confirm grip and free ends
Collar flange bolts | 4 | M3 × 12 with nuts/washers | Fit trial
Base lid screws | 4 | M3 × 12 into trapped M3 nuts | Fit trial
Controller carrier ties | 60 | 2.5 mm nylon cable ties | 3 open saddles per carrier
Controller board screws | 80 | M2, select length after perfboard and spacer trial | No electrical contact with traces
Non-slip feet | 4 | Adhesive rubber, under base near R94 | Retention, floor friction and tip test
Wire and connectors | 1 | AWG24 power, twisted RS485 pair, precrimp 6-pin JST-SH tile leads | Quantities/lengths from harness schedules; add strain relief
Bench qualification components | 1 | See dedicated bench BOM and prototype table | Separate from full-globe quantities

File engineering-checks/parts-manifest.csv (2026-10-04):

part | quantity | material | process | volume_each_mm3 | STL | STEP
base-cup | 1 | PA12 | SLS/MJF PA12 | 155674.178 | True | True
base-lid | 1 | PA12 | SLS/MJF PA12 | 93879.082 | True | True
ballast-150D-6T | 1 | mild steel | machined purchased metal | 104284.037 | True | True
base-collar-half--1 | 1 | PA12 | SLS/MJF PA12 | 9475.325 | True | True
base-collar-half-+1 | 1 | PA12 | SLS/MJF PA12 | 9475.332 | True | True
controller-carrier-01 | 1 | PA12 | SLS/MJF PA12 | 4494.488 | True | True
controller-carrier-02 | 1 | PA12 | SLS/MJF PA12 | 4487.642 | True | True
controller-carrier-03 | 1 | PA12 | SLS/MJF PA12 | 4593.947 | True | True
controller-carrier-04 | 1 | PA12 | SLS/MJF PA12 | 4593.942 | True | True
controller-carrier-05 | 1 | PA12 | SLS/MJF PA12 | 4593.961 | True | True
controller-carrier-06 | 1 | PA12 | SLS/MJF PA12 | 4487.66 | True | True
controller-carrier-07 | 1 | PA12 | SLS/MJF PA12 | 4593.97 | True | True
controller-carrier-08 | 1 | PA12 | SLS/MJF PA12 | 4494.481 | True | True
controller-carrier-09 | 1 | PA12 | SLS/MJF PA12 | 4487.627 | True | True
controller-carrier-10 | 1 | PA12 | SLS/MJF PA12 | 4487.576 | True | True
controller-carrier-11 | 1 | PA12 | SLS/MJF PA12 | 4494.474 | True | True
controller-carrier-12 | 1 | PA12 | SLS/MJF PA12 | 4494.526 | True | True
controller-carrier-13 | 1 | PA12 | SLS/MJF PA12 | 4494.494 | True | True
controller-carrier-14 | 1 | PA12 | SLS/MJF PA12 | 4494.51 | True | True
controller-carrier-15 | 1 | PA12 | SLS/MJF PA12 | 4527.423 | True | True
controller-carrier-16 | 1 | PA12 | SLS/MJF PA12 | 4487.625 | True | True
controller-carrier-17 | 1 | PA12 | SLS/MJF PA12 | 4487.546 | True | True
controller-carrier-18 | 1 | PA12 | SLS/MJF PA12 | 4487.599 | True | True
controller-carrier-19 | 1 | PA12 | SLS/MJF PA12 | 4487.632 | True | True
controller-carrier-20 | 1 | PA12 | SLS/MJF PA12 | 4593.933 | True | True
base-electronics-carrier | 1 | PA12 | SLS/MJF PA12 | 8332.03 | True | True
cage-octant-01 | 1 | PA12 | SLS/MJF PA12 | 36962.817 | True | True
cage-octant-02 | 1 | PA12 | SLS/MJF PA12 | 48171.61 | True | True
cage-octant-03 | 1 | PA12 | SLS/MJF PA12 | 46904.017 | True | True
cage-octant-04 | 1 | PA12 | SLS/MJF PA12 | 44211.393 | True | False
cage-octant-05 | 1 | PA12 | SLS/MJF PA12 | 47317.387 | True | True
cage-octant-06 | 1 | PA12 | SLS/MJF PA12 | 49257.593 | True | True
cage-octant-07 | 1 | PA12 | SLS/MJF PA12 | 52569.025 | True | True
cage-octant-08 | 1 | PA12 | SLS/MJF PA12 | 52850.507 | True | True
prototype-cradle-type-02 | 1 | PA12 | SLS/MJF PA12 | 6199.282 | True | True
spine-12OD-8ID-314L | 1 | 6061 aluminum; deburr 6 mm cable exit | machined purchased metal | 19669.484 | True | True
spoke--1-1 | 1 | 6061 aluminum | machined purchased metal | 3824.248 | True | True
spoke--1-2 | 1 | 6061 aluminum | machined purchased metal | 3824.233 | True | True
spoke--1-3 | 1 | 6061 aluminum | machined purchased metal | 3824.252 | True | True
spoke--1-4 | 1 | 6061 aluminum | machined purchased metal | 3824.25 | True | True
spoke--1-5 | 1 | 6061 aluminum | machined purchased metal | 3824.252 | True | True
hub--1-half--1 | 1 | PA12 | SLS/MJF PA12 | 5365.933 | True | True
hub--1-half-+1 | 1 | PA12 | SLS/MJF PA12 | 5829.991 | True | True
spoke-+1-1 | 1 | 6061 aluminum | machined purchased metal | 3824.244 | True | True
spoke-+1-2 | 1 | 6061 aluminum | machined purchased metal | 3824.248 | True | True
spoke-+1-3 | 1 | 6061 aluminum | machined purchased metal | 3824.252 | True | True
spoke-+1-4 | 1 | 6061 aluminum | machined purchased metal | 3824.262 | True | True
spoke-+1-5 | 1 | 6061 aluminum | machined purchased metal | 3824.249 | True | True
hub-+1-half--1 | 1 | PA12 | SLS/MJF PA12 | 5830.0 | True | True
hub-+1-half-+1 | 1 | PA12 | SLS/MJF PA12 | 5365.839 | True | True
pcb-outline-type-00 | 1 | FR4 1 mm | PCB / reference geometry | 560.515 | False | True
pcb-outline-type-01 | 1 | FR4 1 mm | PCB / reference geometry | 705.476 | False | True
pcb-outline-type-02 | 1 | FR4 1 mm | PCB / reference geometry | 741.046 | False | True
pcb-outline-type-03 | 1 | FR4 1 mm | PCB / reference geometry | 821.634 | False | True
pcb-outline-type-04 | 1 | FR4 1 mm | PCB / reference geometry | 741.046 | False | True
pcb-outline-type-05 | 1 | FR4 1 mm | PCB / reference geometry | 867.226 | False | True
baffle-type-00 | 36 | opaque black resin; qualify 0.4 mm walls | SLA/DLP resin | 1583.728 | True | False
baffle-type-01 | 43 | opaque black resin; qualify 0.4 mm walls | SLA/DLP resin | 2227.002 | True | False
baffle-type-02 | 48 | opaque black resin; qualify 0.4 mm walls | SLA/DLP resin | 2380.745 | True | False
baffle-type-03 | 42 | opaque black resin; qualify 0.4 mm walls | SLA/DLP resin | 2775.031 | True | False
baffle-type-04 | 42 | opaque black resin; qualify 0.4 mm walls | SLA/DLP resin | 2380.551 | True | False
baffle-type-05 | 15 | opaque black resin; qualify 0.4 mm walls | SLA/DLP resin | 2766.904 | True | False
magnet-seat-M2-4mm | 60 | PA12; magnet pocket 4.2 mm | SLS/MJF PA12 | 100.662 | True | False
pcb-head-spacer-M2 | 652 | PA12 or purchased nylon; lifts screw head above LEDs | PCB / reference geometry | 5.805 | True | False
magnet-fit-coupon | 1 | same process as magnet seats | PCB / reference geometry | 1686.762 | True | False
terrain-shell-01-25x | 1 | translucent optical resin with qualified charcoal finish | SLA/DLP resin | 23016.997 | True | False
terrain-shell-02-25x | 1 | translucent optical resin with qualified charcoal finish | SLA/DLP resin | 17179.828 | True | False
terrain-shell-03-25x | 1 | translucent optical resin with qualified charcoal finish | SLA/DLP resin | 15320.159 | True | False
terrain-shell-04-25x | 1 | translucent optical resin with qualified charcoal finish | SLA/DLP resin | 14929.144 | True | False
terrain-shell-05-25x | 1 | translucent optical resin with qualified charcoal finish | SLA/DLP resin | 16718.421 | True | False
terrain-shell-06-25x | 1 | translucent optical resin with qualified charcoal finish | SLA/DLP resin | 18837.464 | True | False
terrain-shell-07-25x | 1 | translucent optical resin with qualified charcoal finish | SLA/DLP resin | 16027.184 | True | False
terrain-shell-08-25x | 1 | translucent optical resin with qualified charcoal finish | SLA/DLP resin | 16919.226 | True | False
terrain-shell-09-25x | 1 | translucent optical resin with qualified charcoal finish | SLA/DLP resin | 14645.936 | True | False
terrain-shell-10-25x | 1 | translucent optical resin with qualified charcoal finish | SLA/DLP resin | 18329.549 | True | False
terrain-shell-11-25x | 1 | translucent optical resin with qualified charcoal finish | SLA/DLP resin | 15996.289 | True | False
terrain-shell-12-25x | 1 | translucent optical resin with qualified charcoal finish | SLA/DLP resin | 16779.455 | True | False
terrain-shell-13-25x | 1 | translucent optical resin with qualified charcoal finish | SLA/DLP resin | 14641.987 | True | False
terrain-shell-14-25x | 1 | translucent optical resin with qualified charcoal finish | SLA/DLP resin | 15404.431 | True | False
terrain-shell-15-25x | 1 | translucent optical resin with qualified charcoal finish | SLA/DLP resin | 15921.795 | True | False
terrain-shell-16-25x | 1 | translucent optical resin with qualified charcoal finish | SLA/DLP resin | 16682.905 | True | False
terrain-shell-17-25x | 1 | translucent optical resin with qualified charcoal finish | SLA/DLP resin | 17307.263 | True | False
terrain-shell-18-25x | 1 | translucent optical resin with qualified charcoal finish | SLA/DLP resin | 14610.817 | True | False
terrain-shell-19-25x | 1 | translucent optical resin with qualified charcoal finish | SLA/DLP resin | 15403.629 | True | False
terrain-shell-20-25x | 1 | translucent optical resin with qualified charcoal finish | SLA/DLP resin | 17644.12 | True | False
prototype-shell-vancouver-25x | 1 | translucent resin; local PCB coordinates | SLA/DLP resin | 1758.709 | True | False
prototype-shell-himalaya-25x | 1 | translucent resin; local PCB coordinates | SLA/DLP resin | 2530.607 | True | False

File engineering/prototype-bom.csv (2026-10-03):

id | item | quantity | allowance_low_usd | allowance_high_usd | reference | check_before_buying
P01 | Adafruit 5201 IS31FL3741 RGB matrix | 1 | 25 | 45 | https://www.adafruit.com/product/5201 | Reference board verified; live stock/price unverified
P02 | Adafruit 5426 QT Py ESP32-S3 | 1 | 15 | 30 | https://www.adafruit.com/product/5426 | Use correct CircuitPython/USB cable
P03 | Adafruit 757 BSS138 I2C level shifter | 1 | 5 | 12 | https://www.adafruit.com/product/757 | Required for reference matrix at 5 V and ESP32 at 3.3 V
P04 | Enclosed regulated 5 V supply and protected connection | 1 set | 20 | 40 |  | Correct polarity; initial 0.5 A branch fuse/current limit; supplier certification
P05 | Leads spacers clamps and screws | 1 set | 15 | 35 |  | Keep power positives separate; common ground
P06 | Translucent coupon/curved-shell print batch | 1 batch | 50 | 150 |  | Service must approve material minimum wall supports and cure
P07 | Smoke tint matte clear diffuser samples | samples | 15 | 35 |  | Confirm compatibility; retain uncoated control
P08 | Calipers multimeter contact temperature probe | borrow or buy | 0 | 80 |  | Needed for geometry current and temperature measurements

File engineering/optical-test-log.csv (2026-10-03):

sample_id | material | process_layer_mm | cure | wall_mm | tint_product_coats | diffuser | minimum_gap_mm | center_gap_mm | pattern | global_current_code | scaling_code | voltage_V | measured_current_A | room_C | surface_C | footprint_halfmax_mm | spill_at_6mm_percent | dark_gap_pass | terrain_pass | notes
flat-0.6
flat-0.8
flat-1.0
flat-1.2
curved-smooth
curved-25x

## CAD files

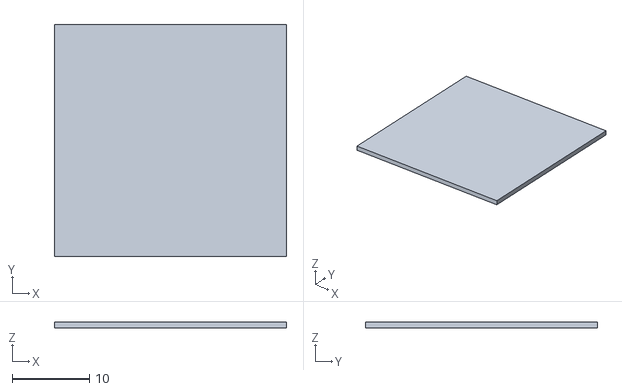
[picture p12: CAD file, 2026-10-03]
engineering/flat-coupon-0.8mm.stl
30.0 x 30.0 x 0.8

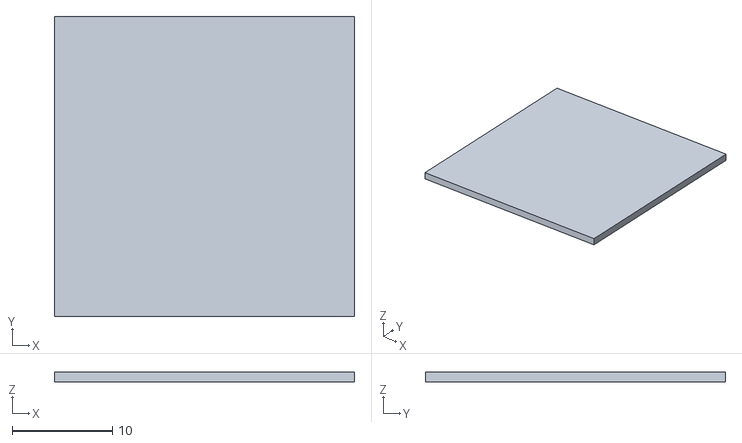
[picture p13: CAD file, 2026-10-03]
engineering/flat-coupon-1.0mm.stl
30.0 x 30.0 x 1.00

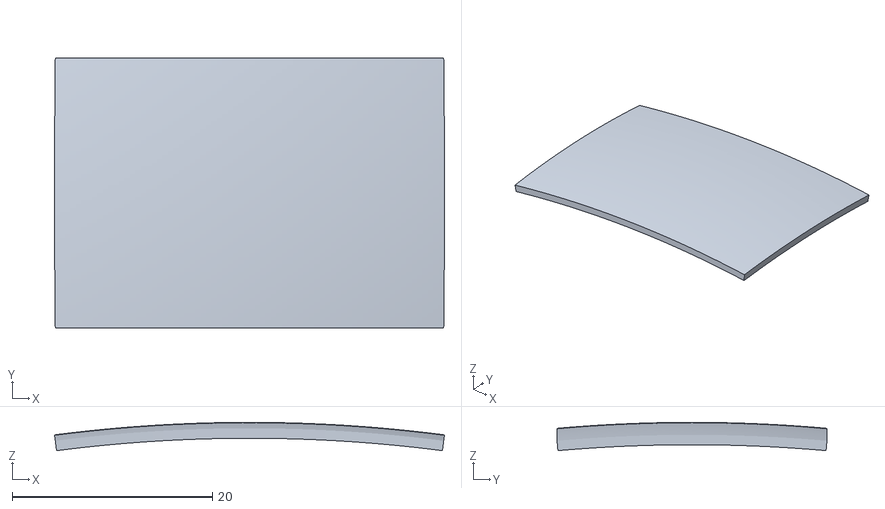
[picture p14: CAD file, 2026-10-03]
engineering/matrix-shell-smooth-mm.stl
39.0 x 27.0 x 2.83

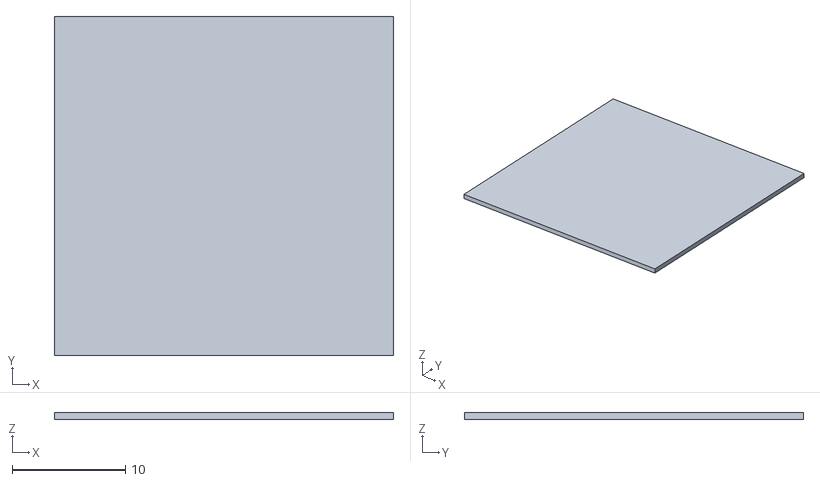
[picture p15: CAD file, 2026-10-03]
engineering/flat-coupon-0.6mm.stl
30.0 x 30.0 x 0.6

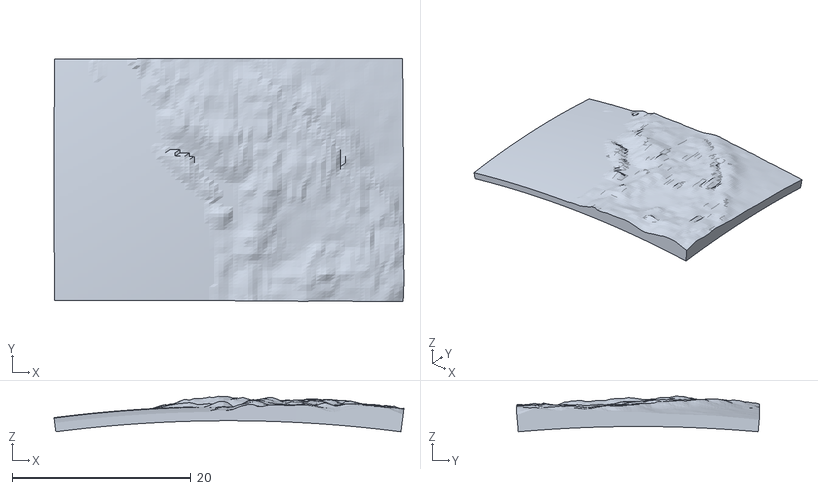
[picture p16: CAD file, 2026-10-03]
engineering/matrix-shell-vancouver-25x-mm.stl
39.1 x 27.2 x 3.98

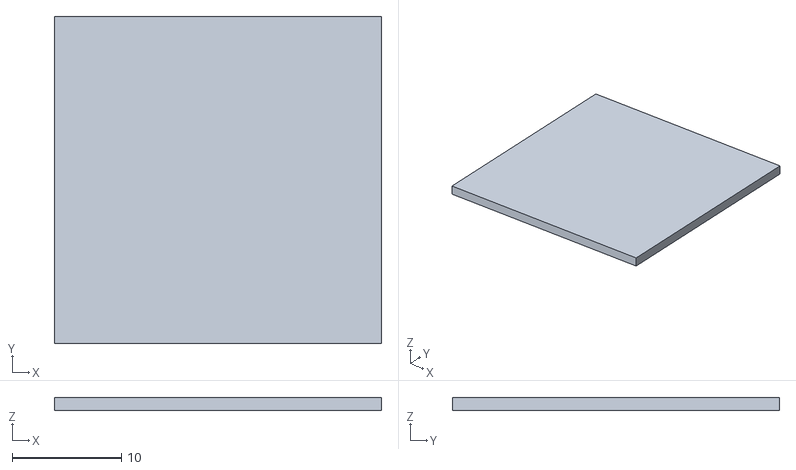
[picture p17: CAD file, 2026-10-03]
engineering/flat-coupon-1.2mm.stl
30.0 x 30.0 x 1.20

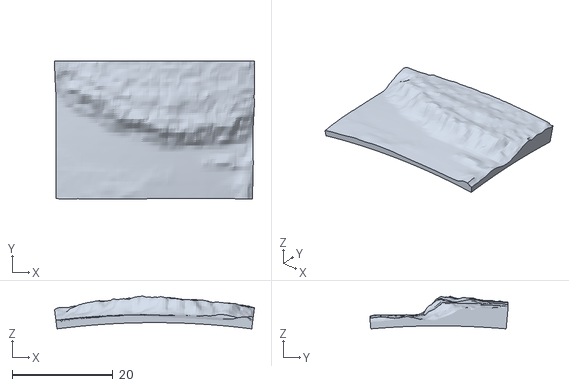
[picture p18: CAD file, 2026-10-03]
engineering/matrix-shell-himalayas-25x-mm.stl
39.6 x 27.4 x 6.50

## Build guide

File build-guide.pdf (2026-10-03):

# Building the travel globe

Design brief: 305 mm sea-level diameter · 25× real terrain · 50-mile visited-area radius · dark charcoal surface · warm amber light.

The recommended route is a serviceable, internally illuminated globe with a thin terrain shell, separate optical cells to limit light spill, and dense LED boards. Store the visited places independently of the physical LED layout. Start with a small illuminated sample; release the full shell and custom electronics only after it passes the tests below.

This package provides a detailed design and checked prototype test files. Full-globe production CAD, custom electronics and device firmware will follow the measured sample results; print material and supports need the service’s review.

Open the simulator (https://trentconley.github.io/globe/index.html) · Explore the structure in 3D (https://trentconley.github.io/globe/structure.html) · Save the PDF guide (https://trentconley.github.io/globe/build-guide.pdf) · Download the build package (https://trentconley.github.io/globe/prototype-kit.zip) · Design calculations (https://trentconley.github.io/globe/engineering/calculations.json) · Parts and quote checklist (https://trentconley.github.io/globe/engineering/prototype-bom.csv)

# 1. What we are designing for

Requirement | Design target
Globe size | 305 mm diameter at sea level; room for the exaggerated mountains outside that sphere
Surface | Real ETOPO-derived terrain, 25× vertical exaggeration; smooth oceans
Travel display | Union of approximate 50-mile-radius footprints around saved places; no inferred routes or country fills
Appearance | Charcoal matte when off; warm amber/gold visited regions; mountains remain recognizable
Geographic resolution | Small regions within countries remain distinct; nearby visits may merge
Persistence | A successfully saved destination survives loss of power; a interrupted save recovers the last valid history
Updates | Local phone/computer interface, plus documented JSON upload/export; no subscription
Longevity | Replaceable lighting modules, removable shell sections, replaceable external supply, offline backups

First acceptance distance Judge appearance at 0.5–1 m, then inspect close up; use normal room lighting as well as a dim room

Initial fabrication | Print service, preassembled boards, basic soldering and mechanical assembly

The 50-mile preference stays the command radius. We will measure the actual illuminated patch after printing. We will not conceal poor resolution by silently changing the stored visit radius.

## The two dimensions that matter most

At this scale, 50 miles corresponds to 1.926 mm radius, or 3.852 mm diameter. A nearby pair of cities can legitimately merge into one small patch.

Travel Globe · 25× / 50 mi · 1 / 18

The current elevation grid's highest sample is 6,229 m. At 25×, it becomes 3.728 mm of raised terrain. A shell with a smooth inside and a 1 mm base wall can therefore become 4.728 mm thick radially under its highest sampled mountains. That thickness is an optical problem worth testing before a large print order.

The full geometric envelope is bounded by about 312.5 mm, although opposite points do not both sit at the highest elevation. Allow this envelope in the stand and packaging. If we later change to finer terrain data, we must recalculate it: a preserved 8,849 m summit would rise about 5.30 mm at 25×. Do not change terrain datasets halfway through manufacturing.

# 2. The architecture I recommend

A modular, rear-lit shell is the leading architecture. The full-globe lighting needs custom preassembled boards; the first optical experiment can use an existing assembled matrix.

From outside to inside:

1. A thin, compatible matte clear finish.
2. A controlled translucent charcoal tint over land; an opaque ocean mask where desired.
3. A printed translucent terrain shell.
4. A very small, measured gap or replaceable soft sealing interface.
5. Opaque light cells/baffles that keep one lit area from flooding its neighbors.
6. Small LED boards, mapped to actual geographic positions.
7. A separate structural frame carrying boards, wiring and shell mounts.

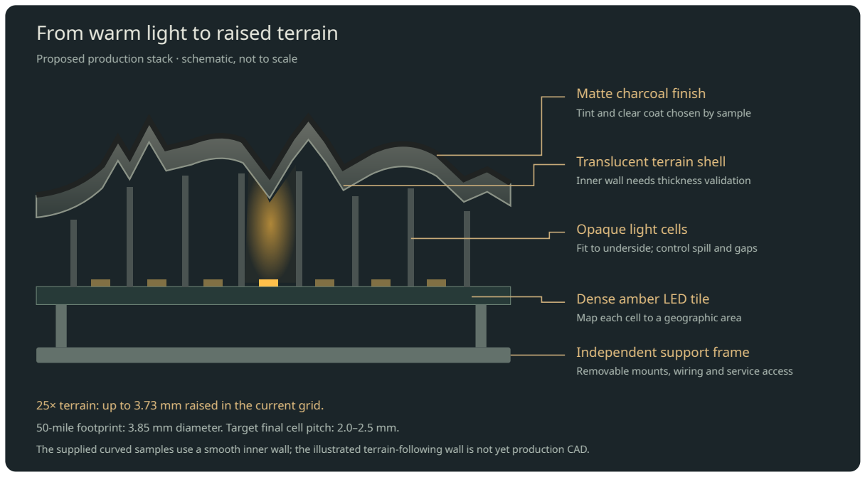
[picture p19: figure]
From warm light to raised terrain; Matte charcoal finish; Translucent terrain shell; Opaque light cells; Dense amber LED tile; Independent support frame; Tint and clear coat chosen by sample; Inner wall needs thickness validation; Map each cell to a geographic area

Proposed production stack · schematic, not to scale

Fit to underside; control spill and gaps

Removable mounts, wiring and service access

25× terrain: up to 3.73 mm raised in the current grid.
50-mile footprint: 3.85 mm diameter. Target final cell pitch: 2.0–2.5 mm.
The supplied curved samples use a smooth inner wall; the illustrated terrain-following wall is not yet production CAD.

The interactive structural study (https://trentconley.github.io/globe/structure.html) adds assembled, cutaway, exploded, frame-only and small-prototype views. It shows proposed space allocations and layer relationships. The terrain samples are printable; the

Travel Globe · 25× / 50 mi · 2 / 18 complete frame joints, carrier brackets, shell mounts, optical cells and electronics remain to be engineered. The full-globe LED dots are representative, not the final pitch or population.

The terrain shell does not carry the globe's weight. Mounts and a frame do that. The electrical and optical assemblies should come apart without destroying the finished exterior.

For the final light source, prefer monochrome amber LEDs if one tested amber wavelength gives the desired appearance. They avoid paying for and powering three channels at every location. Buy enough of one optical bin/lot for the whole globe plus spares. If the coating makes monochrome amber too orange, or adjustable gold is important, use a tested two-color amber/warm-white or RGB implementation and recalculate every channel, power, and cost estimate.

A monochrome driver bank does not require a tiny controller inside every LED. That matters: thousands of addressable RGB packages can consume substantial power even when their colors are set to black. Measure idle current rather than assuming sparse visits make the whole globe low power.

## Why not use the earlier strips?

A 144-LED/m strip has roughly 6.94 mm longitudinal spacing, already larger than a 3.85 mm footprint. The earlier six-strip layout is coarser still in its other direction. It is useful for trying color or tint, but it is not the recommended resolution test or final construction.

## Why not wrap a large flexible matrix around it?

A sphere curves in two directions. A flexible rectangular PCB generally bends easily in one direction but cannot cover a sphere without stretching, wrinkling, cuts, or segmentation. Narrow flex gores are an alternative development project, not something to assume will fit because a vendor calls a panel flexible.

## Why not put one projector inside?

Projection is attractive for resolution, but a full sphere needs suitable optical coverage, focus over different distances, alignment, and management of supports and shadows. The raised translucent surface adds another optical variable. It is not the simplest route to a quiet, repairable, one-foot object. Revisit projection if dense LEDs fail the optical test; do not promise a one-projector solution now.

# 3. Lighting resolution and full-globe complexity

These are equal-area square-cell estimates, not a finished PCB layout. Oceans occupy roughly 71% of Earth, but coastline margins, board packing, seams and small islands prevent the land-area column from being a final purchasing quantity.

Travel Globe · 25× / 50 mi · 3 / 18

Nominal cell pitch | Cells across one 50-mile footprint | Whole-sphere area / pitch² | Land-area lower-bound estimate
2.0 mm | 1.93 | 73,062 | 21,188
2.5 mm | 1.54 | 46,759 | 13,560
3.0 mm | 1.28 | 32,472 | 9,417
6.94 mm | 0.55 | 6,060 | 1,757

Design toward 2.0–2.5 mm effective surface pitch. Treat 3 mm as a readily available first test and a possible compromise only if the physical result is satisfying. Even 2 mm gives only about two samples across an isolated footprint; this is an approximate regional display, not a sharp little geographic screen.

A 3 mm matrix that looks good is useful evidence. It does not establish that a lower-density strip will look equally good. Conversely, if one isolated visit disappears between 3 mm emitters, it is a reason to test finer pitch—not to light the entire country.

The mapping must sample coverage over each cell's area, rather than checking only its center. Otherwise a small footprint can vanish between emitters. Store the geographic footprint first, then calculate light levels for the installed layout. Neighboring footprints combine by maximum/union, so overlapping visits do not become artificially brighter.

## Provisional full-globe segmentation

Use small, approximately planar electronics tiles on a spherical internal frame, with individually shaped optical baffles between each tile and the shell. An icosphere with 320 triangular faces is a useful mechanical starting study because its facets are small; it is not a released 320-board shopping list.

Populate land-bearing areas and coastal margins; use structural blanks over deep ocean. The final tessellation, LED placement, coastline margins, small-island coverage and mechanical shadows must be computed together. About 25,000–40,000 monochrome emitters is a planning range for a fine land-focused implementation, not a verified final count. Cost the all-surface alternative as an upper comparison.

The custom-board designer should aim for repeated PCB shapes, modest numbers of distinct assembly variants, and connectors accessible from the inside. Avoid a different unique PCB design for every geographic patch. Geography belongs in the mapping file and optical shell.

Require an actual pixel-to-surface map before releasing electronics: panel ID, driver ID, electrical channel, LED center, surface intersection, latitude/longitude, optical-cell boundary, calibration gain, and valid/blocked status. Include seams, mounting ribs and coastline masks in the coverage audit. Software cannot illuminate an island for which no physical light path exists.

# 4. Build the optical prototype first

The most useful first purchase is one assembled dense matrix, not enough LEDs for the whole globe.

Travel Globe · 25× / 50 mi · 4 / 18

## Reference prototype electronics

Adafruit IS31FL3741 13×9 RGB matrix, product 5201, is a verified starting board. Its open hardware documentation specifies 117 RGB LEDs at 3 mm pitch, with 8-bit PWM per color element, adjustable global current, I²C, and a 3.3–5 V supply.

The checked PCB revision has a 39 × 51.08 mm board outline. The nominal active cell area is 39 × 27 mm, with LED centers spanning 36 × 24 mm. Do not confuse the board outline with its illuminated area or order a 39 × 27 mm enclosure for the entire board.

Use an Adafruit QT Py ESP32-S3, product 5426, as a compact prototype controller. The checked board documentation describes Wi-Fi, native USB, 8 MB flash and 512 KB SRAM, without PSRAM. It is sufficient for a small matrix experiment and a modest local update interface; it is not yet the full globe's final electronics design.

These are actual identified parts. Availability and delivered prices have not been verified. The electrical reference design, rather than a shop description alone, determines the wiring.

## A crucial wiring detail

The checked matrix schematic connects SDA and SCL pull-ups to the matrix supply. If the matrix is powered at 5 V, its I²C lines must not connect directly to ESP32 GPIO. This is why the recommended 5 V bench arrangement includes a bidirectional I²C level shifter.

Use an Adafruit 757 (https://www.adafruit.com/product/757) BSS138 I²C level-shifter breakout with separate LV/HV references and pull-ups; confirm its supplier documentation. A 74AHCT125 strip-data buffer is not a replacement for a bidirectional I²C shifter.

Connection | Bench arrangement
Controller power | USB from the programming computer
Matrix VCC | Separate regulated, enclosed 5 V supply, initially current-limited where possible
Matrix GND | Supply ground and controller ground
Level shifter LV | Controller 3.3 V
Level shifter HV | Matrix 5 V
Level shifter GND | Shared ground
Controller SDA/SCL | Low-voltage side of the two I²C channels
Matrix SDA/SCL | Corresponding high-voltage side
Optional matrix shutdown | Leave as the documented board default initially; add a properly level-compatible hardware blanking control later
Power positives | Do not join the external matrix 5 V to the controller's USB supply

Travel Globe · 25× / 50 mi · 5 / 18

Use the board's documented STEMMA/QT I²C port in firmware and verify the actual pin labels. Do not assume the controller's edge-header I²C pins and QT connector use the same bus. A normal four-wire plug-to-plug cable bypasses the needed level shifting in this 5 V arrangement; use breakout leads or an interposer.

Keep bench I²C leads around 100 mm where practical and begin at 100 kHz. With power applied and no bus traffic, measure about 3.3 V on the controller-side SDA/SCL and about 5 V on the matrix side before connecting the controller.

Start with low global current and one dim pixel. A protected 5 V, 2 A adapter is a reasonable bench supply class, not a statement that this board may safely consume 2 A. Use a temporary 0.5 A branch fuse or a current-limited bench supply, and verify actual board current/temperature before increasing brightness. Resolve repeated fuse trips rather than substituting a larger fuse.

## Prototype shopping and quote list

Planning allowances in USD, not live prices:

Item | Quantity | Allowance | Release condition
Adafruit 5201, assembled 13×9 matrix | 1 | $25–45 Confirm exact board and revision
Adafruit 5426, QT Py ESP32-S3 | 1 | $15–30 | Confirm matching USB cable
Adafruit 757 I²C level-shifter breakout | 1 | $5–12 Verify LV/HV topology and pull-ups
Enclosed regulated 5 V supply, leads, fuse holder/fuse | 1 set | $20–40 | Correct polarity; no exposed mains
Breakout leads, spacers, screws, temporary clamps | 1 set | $15–35 No load on USB/QT connectors
Translucent coupon and curved-shell print batch | 1 batch | $50–150 | Quote approved material and supports
Compatible smoke tint, matte clear, diffuser samples | Small samples | $15–35 Service confirms compatibility
Calipers, multimeter, contact temperature probe | Borrow if possible | $0–80 | Needed for measurements

The table totals roughly $145–427 before tax/shipping. A sensible first-stage allowance is $200–400, depending on tools and print-service minimums. Do not buy full-globe quantities yet.

## Printable test pieces included

The build package's engineering folder contains:

Four 30 × 30 mm flat coupons, at 0.6, 0.8, 1.0 and 1.2 mm thickness.
A smooth curved shell at the globe's real radius, nominal 39 × 27 mm.
A Vancouver terrain shell over the same area, at 25× elevation, with a 1 mm radial base wall. A second terrain shell centered on the Himalayas, to challenge the stack with much taller land. A land-clipped, area-sampled 13×9 Vancouver test pattern and scale calculations.

Travel Globe · 25× / 50 mi · 6 / 18

A dim, manually selected CircuitPython bench-pattern utility with setup instructions; it is not the final device firmware and has not run on physical hardware.

The terrain coupon's actual bounding box is about 39.14 × 27.22 × 3.98 mm. The smooth coupon is 39.00 × 27.00 × 2.83 mm. Both are closed meshes; they have no fitted mounts, supports or baffles. They are optical test pieces, not released pieces of the final enclosure. STL units must be interpreted as millimetres.

The smooth sphere drops about 1.86 mm between the center and the 39 × 27 mm rectangle's corners. A flat display cannot therefore sit the same distance from every point of this curved shell. Hold the shell with adjustable edge spacers; begin around 0.5–1.0 mm clearance at its closest inside point, measure the resulting center gap, and avoid contact with LED packages.

Cover unused board regions with a removable opaque mask, keep vents and electronics unobstructed, and center the matrix's active region under the shell. Do not glue the coupon to the LEDs.

# 5. Qualify the surface and optical stack

## Material recommendation

Use a print service experienced with translucent SLA/MSLA parts and optical appearance samples. Ask for a tough, dimensionally stable resin with documented cure, finishing compatibility and indoor aging behavior. Do not choose ordinary brittle clear hobby resin solely because it is transparent.

The preferred surface is lightly diffusing, not crystal-clear. A clear window can reveal the individual LEDs; too much white pigment or diffusion can turn a small footprint into a large fuzzy blob.

FDM natural PETG is a cheaper comparison sample, but visible layer texture and inconsistent scattering may fall short of the desired object. Do not order the light-transmitting land surface in opaque black. Painting an opaque white print black does not create a good backlit display.

## Run the flat-coupon experiment first

For each practical thickness, compare:

1. Uncoated printed material.
2. A light translucent smoke coat.
3. A second controlled tint level.
4. The best tint with a thin compatible matte clear.

Label samples on removable tabs or their backs. Record print material, printer/process, layer height, orientation, cure, sanding, tint product, coat count and drying time. Keep one uncoated control.

If neutral-density film samples are available, 0.3/0.6/0.9 optical density corresponds nominally to about 50%/25%/12.5% transmission. They are useful controls, not a prediction that a charcoal coating will transmit

Travel Globe · 25× / 50 mi · 7 / 18

amber the same way.

Try the screen's desired amber by eye under the final coating. A computer RGB value is not a physical wavelength specification. Later compare nominal 590–595 nm amber LED samples from a supplier against the RGB prototype. Commit to one color/bin only after that comparison.

## Then compare the curved pieces

Run identical patterns through the smooth and terrain shells at identical current and exposure. Compare mountain peaks with nearby valleys. Include the supplied Himalayan sample: a Vancouver-only test cannot establish performance under the globe’s highest terrain.

The supplied terrain shell has a smooth inside, so its raised land adds material. It is intentionally a useful test of the simple construction. If peaks go dark while valleys bloom, increasing every LED's current will not solve the underlying mismatch.

The preferred production investigation is a terrain-following inner surface that keeps optical wall thickness closer to constant. It needs proper CAD work: simply subtracting 1 mm from every radius does not guarantee a 1 mm wall measured perpendicular to a steep slope. A normal-offset surface can self-intersect in tight valleys. Smooth/filter only features that cannot satisfy a verified minimum wall, and show that revised geometry in the simulator before approval.

A production CAD release must include a thickness map and interference checks. A thinner shell is not automatically better if it is fragile, warps after curing, or produces visible LED dots.

## Light isolation

Test three conditions in order:

1. Bare matrix behind the coupon.
2. A thin diffuser at a measured location.
3. Opaque cell dividers between sources, with the diffuser close to the emitting surface.

For the 3 mm matrix, a starting divider-wall study is about 0.3–0.5 mm wall thickness with apertures around 2.5–2.7 mm. These are fabrication trial dimensions, not a released baffle STL. A service must confirm that the chosen opaque process produces continuous light-tight walls at those dimensions.

Baffle tops should follow the shell underside. A gap that leaks laterally defeats their purpose; hard contact that point-loads a fragile terrain shell is also undesirable. Investigate a thin compliant seal or controlled contact lands, while keeping the active aperture clear. Measure and prototype the actual assembled gap.

Avoid deep narrow tubes if possible: they discard light, make alignment harder and produce a visible honeycomb. If a flat board requires very long cells near a curved shell, use smaller boards or a different segmentation instead of making every tube longer.

Travel Globe · 25× / 50 mi · 8 / 18

## Acceptance tests before full-globe CAD

Use a fixed camera exposure for comparisons and a ruler in the same plane. Phone auto exposure can make two different stacks look equally bright.

Test | Target or decision
Off-state appearance | Satisfying dark charcoal at normal room illumination, without obvious white plastic, pixels or grid
One visited place | Clearly visible local amber area, not a country fill
Isolated footprint size | Aim for roughly 3.5–6 mm apparent diameter; measure at half-maximum brightness where practical
Dark separation | Two commanded 50-mile footprints 8 mm apart should retain a visible dark gap
Spill | At a point about 6 mm from an isolated visit's center, aim for less than 10% of the patch's peak signal above background
Overlap | Nearby visits merge without a brighter seam or a connecting route
Terrain | The Rockies/coastal ranges read as terrain; peaks do not disappear because they are too opaque
Tint/current | Good color at a modest measured current, without a glowing white haze
Thermal trial | Surface below 40°C in a 25°C room as an initial comfort target; no material distortion
Repeatability | A second piece with the same process gives similar finish and transmission

The numerical optical targets are design acceptance targets, not measured results. If the apparent footprint is consistently 7–10 mm, that represents a noticeably broader area than the simulator. Record it and decide explicitly whether it is acceptable before changing hardware density or the preview.

If 3 mm pitch passes the look test but an isolated place is poorly placed or disappears, commission one finer-pitch tile. If 2–2.5 mm pitch still fails through the chosen shell, fix the optics before scaling up.

# 6. Full shell, frame and mechanical design

## Exterior

Keep the approved 25× elevation mesh and the lighting map under revision control. The displayed coastlines and grid are simplified; they are adequate for a first regional object, but small-island completeness needs a deliberate check before final manufacture.

Ask for a finish sample in the exact final material. Specify outer surface quality before an invisible internal dimensional detail. Prefer support placement on inward surfaces or sacrificial mounting tabs, not mountain ridges.

Divide the exterior into removable sections sized for the selected printer and assembly access. Let the fabrication service and mechanical designer choose the final count after orientation, shrinkage, frame

Travel Globe · 25× / 50 mi · 9 / 18 support and seam studies. Eight to twelve external sections is a starting packaging concept, not a frozen geometry; their boundaries need not match the smaller electronics tiles.

Place seams primarily in ocean regions where possible. Use a light-blocking internal overlap/labyrinth and registration features. Do not permanently bond every seam shut. Test a 0.15–0.30 mm visible joint study with the actual process rather than specifying an impossible zero-width seam.

Keep fasteners and locating features on hidden inward flanges. Small screws into separate inserts or nuts are preferable to repeated tightening into thin resin. Insert installation must not crack or distort the optical shell. Use one locating datum and allowances for expansion rather than over-constraining every edge.

## Frame and service access

Use an internal spine and removable carriers. The shell should locate onto these carriers while the frame supports gravity and handling. Route wiring along members and leave a service loop at each removable section.

Use keyed, labeled connectors and panel IDs that match the mapping file. Make it possible to replace one failed module without desoldering neighboring modules or removing every shell segment.

Maintain a keep-out envelope between the tallest component, connectors, baffles and shell. Include fastener heads, wire bend radius and strain relief, not just the PCB outline. Audit every mechanical obstruction against the light map.

## Stand

Use a weighted base, roughly 180–220 mm in diameter as a starting layout, with non-slip feet and a replaceable power connector. A charcoal body with restrained brass/amber details fits the visual direction.

Design tilt and service access before routing the cable. A fixed globe is the lowest-risk first build. If hand rotation is desired, use bearings with a controlled rotation range, mechanical stops and a protected cable loop. Unlimited rotation needs a properly rated slip ring and introduces another wear component; a motor is unnecessary for the first version.

Account explicitly for any support opening near the south pole. It is a real non-display region and should appear in the physical coverage map rather than being hidden by software claims.

Stability must be calculated from the measured completed mass and center of gravity. As an initial check, a 2.2 kg object on a 200 mm diameter base resists roughly 5.4 N of horizontal force applied 400 mm above the support plane before idealized tipping. This ignores sliding and mounting compliance. Test the actual assembly with a controlled gentle force; do not rely on that example if the globe or base weights change.

Travel Globe · 25× / 50 mi · 10 / 18

# 7. Full-globe electronics

## LED boards

A custom monochrome matrix around an IS31FL3741-class driver is a credible starting point. The checked Adafruit implementation addresses 351 monochrome channels and provides global current, per-channel scaling, PWM, reset and output enable. Those capabilities suit a slowly updated travel display.

This is not approval to copy a board and substitute amber LEDs blindly. The PCB engineer must verify the manufacturer's current datasheet: scan arrangement, peak versus average LED current, current-setting resistor, compliance voltage, LED pulse rating, thermal limits, decoupling, reset behavior and failure states. The direct datasheet was inaccessible in this research environment, so those details remain procurement/release checks.

The prototype board's RGB channel mapping and current resistor values are not automatically correct for a full amber panel. Order assembled boards; thousands of tiny LED joints are not an appropriate hand-soldering task.

Freeze LED orientation, bin, resistor values, driver revision, connector orientation and test points before a production lot. Supply a factory test pattern that lights each channel in turn, tests all-off leakage, verifies communication and records panel current.

## Control network

One Wi-Fi controller owns the travel history and exposes the user interface. For the production main board, prefer an ESP32-S3 variant with external PSRAM and enough flash for A/B firmware plus separate history, mapping and calibration partitions; 8 MB PSRAM and 16 MB flash are useful design targets to verify against the selected module. The no-PSRAM QT Py is the bench controller, not a frozen full-globe memory configuration. For the finished globe, use several local sector controllers so long wiring runs do not turn a large I²C bus into an intermittent display.

A practical starting topology is one main ESP32-S3 plus four sector controllers. Connect sectors using a properly designed differential link such as RS-485, with addressed packets, CRC, acknowledgments and retry limits. Select a transceiver compatible with the logic rail; the final schematic must specify termination, biasing, ESD protection and grounding.

Each sector has short local I²C branches to its driver boards. Address multiplexers can separate repeated driver addresses and reduce connected capacitance. The reference matrix supports four addresses; an eight-channel multiplexer can select branches containing up to four distinct addresses, subject to actual board electrical loading. A multiplexer is not a magic cure for long wires or excessive pull-ups.

The complete network must be checked with an oscilloscope for rise time, logic levels, noise and recovery at the selected bus rate. Start conservatively. This display changes when travel history or brightness changes;

Travel Globe · 25× / 50 mi · 11 / 18 it does not require video bandwidth.

A transfer of 25,000 one-byte brightness values takes at least 2.25 s at 100 kbit/s I²C before register/page/branch overhead. Sectoring and selective updates help. Target an acknowledged update within about five seconds; do not advertise instantaneous full-frame changes before measuring the actual topology.

## Power distribution

Keep mains outside the object in a certified enclosed adapter. Distribute a higher low voltage, provisionally 12 V, through separately protected branches, and regulate locally near LED sectors. The final supply size follows measurement; an adjustable 30–60 W class architecture provides development headroom but is not permission to dissipate that much continuously inside a closed globe.

With 20,000 active amber LEDs, average current per LED gives the following lower-order rail estimates:

Average current per LED | LED rail current | Power at a 3.3 V LED rail
0.05 mA | 1 A | 3.3 W
0.10 mA | 2 A | 6.6 W
0.20 mA | 4 A | 13.2 W
0.50 mA | 10 A | 33 W

For 40,000 active emitters, double the LED figures above. These exclude controller/driver idle current, regulators and wiring losses. They are average currents through LEDs, not the multiplexed driver's instantaneous setting. Include scan duty cycle, PWM and worst-case enabled channels when specifying peak current.

Aim for roughly 10–15 W or less in the eventual normal indoor display, then measure whether the optics make that feasible. Full-land service-test mode must be subject to a measured power cap. Do not base wire sizing on the optimistic assumption that only Vancouver will ever be illuminated.

Use branch protection and connectors rated for the actual worst-case current. Calculate voltage drop using the complete outgoing and return path: voltage loss is current times total resistance. Keep LED power out of development-board USB traces and small signal connectors.

Provide hardware blanking/current limiting and sensible protection independent of ordinary brightness software. If firmware crashes or a driver powers up incorrectly, the result should not be an unbounded full-current display.

## Thermal design

Travel Globe · 25× / 50 mi · 12 / 18

Design for passive cooling first: low operating power, a conductive support path, and discreet ventilation where it does not create light leaks. Add temperature sensing near a representative warm LED region and near the power conversion electronics.

Measure at least all-off, typical travel history, a dense visited region and a current-limited all-land test. Log supply current and temperatures for at least two hours or until stable. Test the finished tinted shell, not an open frame only.

Use the actual resin/coating's service temperature and component derating curves. A comfort target of 40°C at the outer surface is not the only limit. Program a lower brightness ceiling or thermal shutdown well below the lowest material/component limit after measuring the warmest locations. Avoid rapid thermal on/off oscillation.

A fan is a fallback, not the default aesthetic. If the desired finish demands too much power, improve transmission or lower internal losses before hiding the problem with a fan.

# 8. Phone updates, storage and software

## What the user should experience

1. Power on: the globe shows the last saved places without requiring internet.
2. Open its local page on a phone/computer on the same network.
3. Add a named location, using latitude/longitude or a deliberate map/geocoder selection.
4. Preview its approximate footprint; save.
5. The globe acknowledges the saved revision and updates its light map.
6. Export a backup whenever desired.

The public GitHub Pages simulator is a design tool. It is not currently connected to a globe. The device will serve its own interface, for example at a local hostname with an IP-address fallback. A public HTTPS page cannot simply be assumed to control an HTTP device on a private LAN; browser security and discovery need deliberate handling.

## Data model

Preserve the existing version-2 travel import/export format: version, radiusMiles, and an array of named latitude/longitude places. Internally add stable IDs, a revision counter, schema version and checksum. Keep hardware panel mapping and brightness calibration in separate versioned files.

Terrain exaggeration is a manufacturing setting once the shell exists. Changing a screen slider does not change a printed mountain. The device's actual shell revision should identify the 25× terrain dataset and geometry.

Travel Globe · 25× / 50 mi · 13 / 18

Do not silently change the meaning of existing visits when installing new LED boards. Re-render the same stored geographic footprints through the replacement board's mapping.

## Persistence that actually survives unplugging

Use a transactional two-slot record scheme:

1. Validate the complete proposed history and size limits in RAM.
2. Write it to the inactive slot with its revision, length and checksum.
3. Commit/flush and read it back.
4. Only then acknowledge success to the phone.
5. On boot, choose the newest complete, valid slot; retain the older slot until a later successful write.

The precise implementation may use an appropriate flash filesystem plus a small NVS manifest, or bounded NVS blobs after checking partition and RAM limits. Do not treat two sequential ordinary file writes as automatically atomic.

Espressif documents NVS recovery under power interruption, with the newly written key/value potentially lost if power is removed during its write. An application-level validated previous record and read-back acknowledgment are still valuable. Write flash on changes, not every display refresh.

Test interruption during each save phase and during firmware update. A save that was acknowledged must remain present after unplugging. An interrupted, unacknowledged save may recover either the old or new complete revision, but never a half-parsed history.

## Network and maintenance

Use a physical setup action and a unique setup/edit credential. Provision onto the home network, then stop exposing an indefinite open setup access point. Keep updates local by default; do not require port forwarding, cloud accounts or a subscription.

Validate input sizes and coordinate ranges, reject malformed data without erasing current history, and require deliberate confirmation for clearing history. Protect write endpoints against unauthenticated or cross-site requests. Keep a USB recovery path.

Use firmware A/B updates with rollback where supported. Do not put travel data in a partition overwritten by firmware flashing. Test upgrade and downgrade handling of stored schema versions before handing over the finished device.

An illustrative eventual API is GET /api/project for export and authenticated PUT /api/project for a complete validated replacement. Its response should include the committed revision/checksum. This API and the device firmware are design requirements, not implemented functionality in the current simulator.

Travel Globe · 25× / 50 mi · 14 / 18

# 9. Calibration and geography

Assemble and calibrate by panel ID, not by guessing LED order.

1. Photograph or inspect each tile's sequential single-pixel test.
2. Record its installed transform relative to the globe coordinate frame.
3. Map each emitter's effective surface cell into latitude/longitude.
4. Apply the land/ocean and mechanical-obstruction masks.
5. Render known calibration locations near the equator, mid-latitudes and high latitudes.
6. Check hemispheres, longitude sign, pole handling and the date line.
7. Measure cell brightness/color through the actual finished shell.

### 8. Apply bounded gain corrections; reduce bright cells rather than driving weak ones past

current/thermal limits.

Calibrate the geographic frame using at least three well-separated recognizable features, and verify additional features. The axes must remain consistent after a shell section is removed and reinstalled.

Include Vancouver alone, separated western North American visits, overlapping Bay Area visits and a date-line case in acceptance tests. Montreal, Edmonton and South Dakota must remain dark for a Vancouver-only history. Add small islands to the final hardware coverage audit; a simplified land polygon can otherwise erase them even if the electronics are dense enough.

The baffle and diffusion stack creates an optical point-spread function. Measure it with a single lit cell. Use that measurement when predicting isolated footprints; the simulator's current coarse-LED comparison is not an optical model.

# 10. Assembly sequence and release gates

Stage | Build | Evidence needed to continue
A | Flat material/tint coupons and the reference matrix | Dark off-state, acceptable amber transmission, known current

B Smooth and 25× curved coupons, spacing and baffle

| trials | Recognizable footprint, controlled spill, acceptable terrain brightness

C One custom fine-pitch tile with its actual baffle and

| shell mount | Real driver/current behavior, reliable mapping, factory assembly quality
D | Two adjacent tiles and one shell joint | Seam appearance, no shadow band, no bright seam, repeatable reassembly
E | One complete serviceable sector with local controller | Power distribution, noise, temperature, update and power-loss tests

F Full frame, limited initial population, then remaining

| sectors | Stable mechanics, correct geographic registration, accessible repair paths
G | Final finish, calibration and endurance testing | Appearance and reliability accepted together

Travel Globe · 25× / 50 mi · 15 / 18

Do not finish-paint all shell sections before the two-section test. Do not buy a full LED lot before confirming optical bin, pitch, driver settings and the factory test process. Do not glue the final shell closed before the endurance and serviceability tests.

A plausible personal-project sequence is several prototype/quote iterations over weeks to months, not a weekend build. Supplier lead time and access to PCB/CAD expertise dominate. The elapsed time is uncertain until the optical result and budget are known.

# 11. Budget and who does what

No budget was available when this package was drafted. The following is a planning envelope, not a quote or authorization to purchase.

Full-globe work/material | Planning allowance
Shell printing, samples, finishing iterations | $300–900
Custom preassembled LED/driver tiles and spares | $500–1,500
Frame, baffles, mounts and weighted base | $200–700
Controller/sector electronics, power, harnesses, connectors | $200–500
Contingency and failed iterations | $300–900
Materials/services subtotal | $1,500–4,500

Professional mechanical/optical/PCB design labor is additional and can add several thousand dollars. That work is not included in a print quote. Prices could move substantially after the tile count and fabrication process are frozen.

For a much lower budget, keep the same 50-mile data model but explicitly reconsider optical pitch, finish, display coverage or assembly ambition after the sample. Do not describe a coarse display as equivalent to the accepted simulator.

Your practical role can be selecting the finish, running sample tests, plugging in preassembled modules, basic soldering, mechanical assembly and maintaining the history. The service should handle high-quality thin-wall printing and finishing. A PCB assembly provider should handle fine-pitch soldering. A qualified electronics/CAD designer should release the custom circuit and production geometry.

## What remains before a full-globe order

Accepted material, tint, diffuser and measured light spread.
Final pitch, LED color/bin, peak/average current and power limits.
Full surface-to-panel mapping, including small islands and support shadows. Production CAD, wall-thickness analysis, seam/mount details and tolerances. Reviewed schematics, PCB files, BOM, harness drawings and factory test procedure.

Travel Globe · 25× / 50 mi · 16 / 18

Device firmware, local update interface, power-loss recovery and recovery flashing procedure. A measured thermal and stability result from the assembled sector.

Those are concrete deliverables, not details to leave to chance during final assembly.

# 12. Print-service request you can copy

I am developing a 305 mm illuminated terrain globe and want a small optical/material test batch first. Please quote the included 30 × 30 mm coupons at 0.6/0.8/1.0/1.2 mm, plus the smooth, Vancouver and Himalayan curved shells. STL units are millimetres; do not resize. The terrain sample uses 25× elevation and has roughly 39.14 × 27.22 × 3.98 mm bounds.

I need a lightly translucent, tough, stable material suitable for indoor backlighting, with a pleasing matte charcoal-tinted off-state and amber transmission when illuminated. Please recommend a resin/process and provide its material data, minimum reliable wall, cure/post-process requirements, dimensional tolerance, expected warping and coating compatibility.

Please keep support marks off the outward display surface where practical, document orientation/layer height/cure, and leave samples uncoated unless we separately agree on a labeled finish trial. These are optical test pieces, not a structural enclosure. Please flag unsupported thin features or damage risks before manufacture and quote a repeat batch using the same process.

# 13. Evidence, files and honest limits

Reference hardware facts were checked against Adafruit's open schematics, board files and library code. Controller storage/update behavior was checked against Espressif documentation. Manufacturer shop pages and several direct datasheet URLs were blocked by the research environment, so current availability/prices, selected resin performance, and the final driver's electrical limits are not independently verified here.

See the hardware source record (https://trentconley.github.io/globe/hardware-sources.html) for exact references and checked facts. The reproducible calculations and coupon generator live in the project source; the ZIP includes their outputs. Prototype mesh checks establish geometry closure and dimensions, not successful printing or measured optical performance.

The next physical action is to obtain one dense matrix and the small sample batch, run the recorded tests, and use those measurements to release one custom tile. That is the shortest responsible path from the look you chose to an excellent object that can be maintained for years.

Travel Globe · 25× / 50 mi · 17 / 18

Travel Globe · Engineering design and prototype package · 25× terrain / 50-mile radius · Print this page to save a PDF.

Travel Globe · 25× / 50 mi · 18 / 18

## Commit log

2026-10-03 Publish visited-area globe simulator and prototype kit
2026-10-03 Use real elevation for globe terrain and printable shell
2026-10-03 Publish 25x globe build design, optical prototypes and engineering guide
    [flat-coupon-0.6mm.stl, flat-coupon-0.8mm.stl, flat-coupon-1.0mm.stl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]
2026-10-04 Publish actual A0 CAD, checked optical prototype and engineering release
    [acceptance-worksheet.csv, budget-allowances.csv, electronics-and-hardware-bom.csv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]
2026-10-04 Add first-sample manufacturing requests and controlled optical test plan
2026-10-05 Publish sample A1 review packs, clearance revision and tested firmware
2026-10-05 Document solder-fit hold in sample A1 review downloads
